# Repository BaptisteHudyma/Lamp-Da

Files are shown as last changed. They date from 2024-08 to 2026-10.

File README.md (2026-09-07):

# Lamp-Da

  

A programmable board integrated with a liion battery charger, battery balancer, multiple sensors and gpios (with 3 analog inputs).

This repository contains the bootloader, software and hardware files to create and program the board.

The system supports programming and charge throught the same USB-C port.

The board is made to fit into a 50mm tube.

## File details
- LampColorControler.ino: main class of the program, containing the setup and loop functions

## Physical build and architecture :

The electrical circuit and build files can be found in the **physical/electrical** folder.

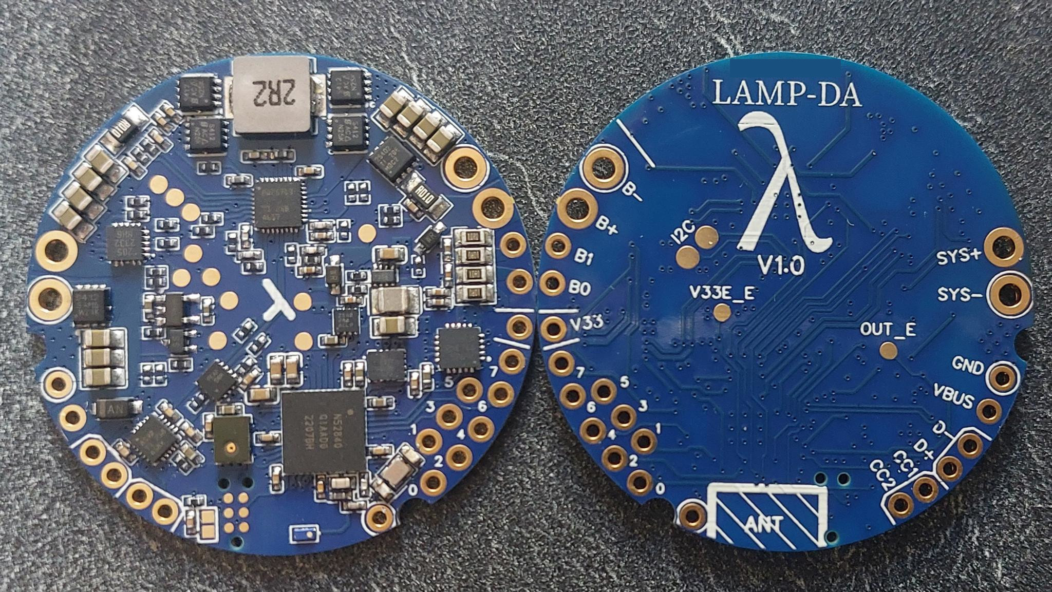
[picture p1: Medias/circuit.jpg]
electrical circuit


The PCB can be ordered directly assembled from JLC PCB, for a total cost of around 270$ for the minimal 5 pieces command (price drops with a more commands, until around 22$/circuit).

The circuit is 3 cells li-ion USB C charger & balancer & power source, that is also programmable via the same USB port.

The circuit features:
- USB-C 3S li-ion charger, based on BQ25713 ic.
- Battery balancing, based on BQ76905 ic.
- USB short circuit and EC protection, based on TPD8S300 ic.
- USB-C power negotiation, base on FUSB302B ic.
- Programable voltage source, from 3V to 20V, up to 3A, using the charge component
- 8 programmable IO pins (3 of which can be analog inputs, 4 can be pwm outputs). Based on nRF52840 ic.
- MEMS Microphone, placed away from parasitic ringing components.
- LSM6DS3TR IMU
- Bluetooth 5.1 low power, with 5/10m range.

- Multiple protection features (ESD spikes protection, USB voltage snubber, USB voltage limitation, ...)

Be careful:
- **NO REVERSE VOLTAGE PROTECTION FOR BATTERY**: it will blow the circuit right up
- **IO are 3.3V max**, any voltage greater will destroy the system

## Update the system

You can update the program without any tools :

Open a serial connection to the lamp, and use the "DFU" command to reset the system.
The system will appear on a computer as a USB file device.

You just need to copy the .uf2 file matching your lamp type into this USB device.
It will then reboot and update the system itself.

## Behavior

The code in this repo is made to be used as compact lanterns.

base behavior:
- The lamp starts and stops with one click.
- The luminosity can be raised by clicking than holding, and diminished by double-clicking than holding.

The battery level is displayed as a color gradient from green (high) to red (low).

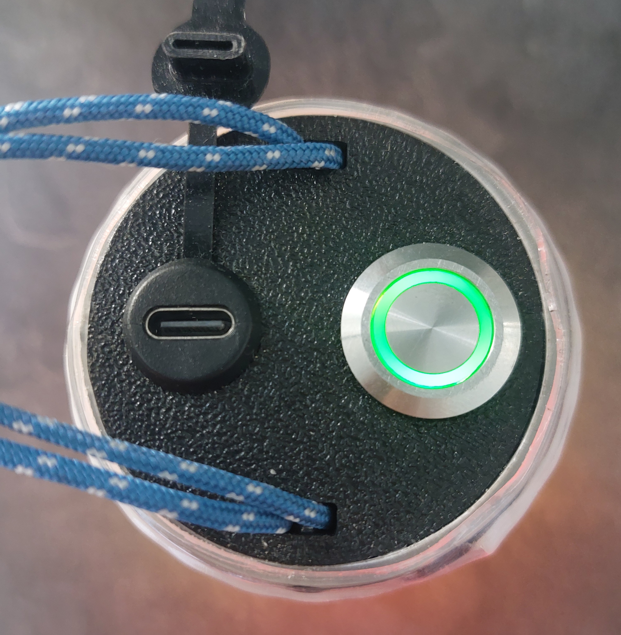
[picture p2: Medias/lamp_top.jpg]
battery levels


Error and alerts are displayed as blinking animations:
- low battery: slow red blinks
- critical battery: fast red blinks, emergency shutdown after short delay
- charging: breeze animation, changing color to indicate battery level
- incoherent battery readings: fast green/red blinks (battery reading do not match the set battery type)
- main loop too slow: fast fushia blinks
- temperature too high: fast orange blinks
- temperature extreme: emergency shutdown
- OTG failed: pink/yellow fast blink (failed to start the output power)
- bluetooth advertising: blue breeze animation
- hardware alert: fast purple/cyan blinks: generic alert to indicate the failure of a component, without recovery
- system off failed : fast purple/white blinks : system failed ot go to sleep, it will reset to default program and will need to be reflashed
- system in error state : fast pink/orange, then shutdown : reached an error state and is stuck here. Shutdown after five seconds
- unhandled: fast white blinks

### User defined behaviors
The user MUST define the target behavior for the target uses.

Some functions are defined in functions.h files, and must be implemented in functions.cpp
They allow the user to program the exact desired behavior.

Some user types are available for base models, in the user folder:
- cct: Program designed for a constant color temperature led strip.
- indexable: program designed for an indexable led strip wrapped around the lamp body
- simple: Program designed for a constant color led strip

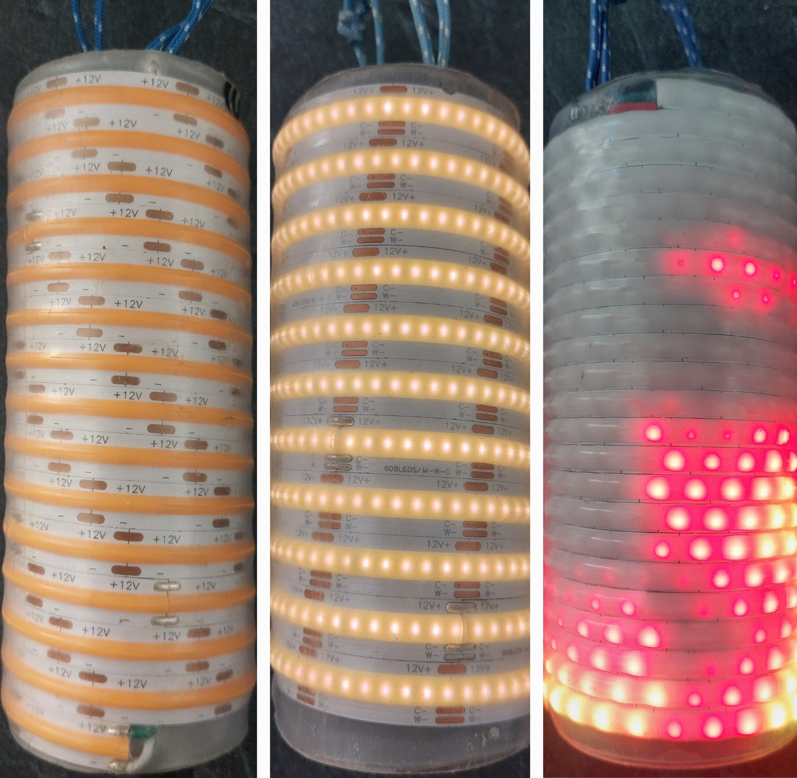
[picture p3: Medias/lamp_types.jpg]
The different lamps

Above: simple, cct, indexable

#### Bootloader flash
Out of factory, the board will miss a bootloader.

- Use a raspberry of any other linux system with gpios
- Use the open source program **openocd** as described in the **flashInfo** folder of this repository.

# Building the project

## Quick Setup

The supported platform to work with the project is:

 - Linux (Debian/Ubuntu/Archlinux/etc)

You will find a full guide on how to build the project here:

 - [Quick Setup](docs/QuickSetup.md) -- also lists all required dependencies

Note that after building documentation, it will be in `docs/html/index.html`

## Other Guides

You will find a guide on how to update the system via USB

 - [Update DFU](docs/Update.md)

You will find a guide on how to setup a virtual machine to build the project:

 - [Virtual Machine](docs/VirtualMachine.md) -- experimental, work-in-progress

You will find contribution guidelines to the project here:

 - [Contributing](docs/Contributing.md) -- **required to read for contributors**

As a beginner, you will find a guide to develop your own lighting mode here:

 - [Writing Modes](docs/WritingModes.md)

And a big thanks to all the people that helped !

 - [Thanks](docs/Thanks.md)

--------------------------------------------

Feel free to open an issue to ask your questions or give your ideas!

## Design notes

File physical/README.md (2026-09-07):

# Physical

Here are the main physical components to build the physical lamp.

## Electrical

Contains the PCB related file : components, routing, layers, everything to build the circuit, or order the circuit alreayd built.

## Objects

The physical objects to 3D print to assemble the lamp.

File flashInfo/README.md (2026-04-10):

# Flash process

When you receive the integrated circuit, the NRF52840 microcontroler will not have a bootloader.

I used a custom bootloader, [derived from adafruit](https://github.com/adafruit/Adafruit_nRF52_Bootloader), that allow the user to program the microcontroler via USB, and update the bootloader itself.

## Bootloader update
When pluging the usb cable, is the board is detected, a bootloader is already flashed.

It can be updated by copying the **update-lampda_nrf52840_bootloader** file into the board.
The board  should appears as a usb drive, with the name **LMBDBOOT**.

If the board  do not appear on the usb board (but is detected on the peripherals), it may be running a program.
The program as a Command Line Interface, that can put the board  in update mode.
Just connect to the board  with a serial connection (command `make monitor` from this repo will open the connection) and send the command `DFU`.

If the board is not detected after being pluged in, and do not appear as a peripheral, and cant be connected with serial, the board may be missing a bootloader.
Follow the next section.

## First time flash

To flash the bootloader for the first time, you must use a computer with GPIOs (I'm using a raspberry Pi) with openocd, or a JTAG connector.

You need to get the **lampda_nrf52840_bootloader**, next to this file.

Raspberry Pi pinout

Wire correspondance:

- white is the CL pin
- brown is the IO pin
- Black is the GND pin
- Red is the 3.3V pin

I use a TC2030 port, programable with a TC2030-MCP-NL cable.
The cable is expensive, but it is only useful once.

Circuit flash pins

You can run openocd next to the openocd.cfg to flash the board.

The process should end with no errors, and openocd should close itself.

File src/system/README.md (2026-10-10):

# File details
- global.h: main entry point for the program
- bsp: Board Support Package. Board specific implementations, under the application, above the HAL.
    - ble_services: BLE custom services
    - pd: PowerDelivery layer
    - balancer.h: handle the battery balancing, and some battery measurments
    - ble.h: BLE high level layer.
    - charging_ic.h: layer of the battery charging component
    - imu_wrappper.h: interaction layer of the imu
    - indicator.h: visual indicator controler (led in the button)
    - filesystem.h: handle the reading and writting of variables to memory
    - power_gate.h: the electrical gates to isolate output & vbus form each others
    - text_in.h: user text input and parsing
    - text_out.h: user text output
    - threads.h: Thread board support
- common: Common general use and interfaces
    - cmd_parser.h: Parse a command to extract its parameters
    - curves.h: define custom curve and curve sampling functions
    - elk_decoder.h: Decode elk messages
    - fft.h: implementation of the fft and assocated filtering
    - state_machine.h: generic state machine class, used for all main logic
    - time_utils.h: Useful time handling function
- component: Medium level physical components layer: button, bluetooth, IMU, ...
    - battery.h: handle the battery readings, for battery level
    - button.h: control the button. Takes callbacks for actions on multiple button pushes. Used to display stuf on the button if needed
    - charger.h: main high level logic to use the charger, as well as power switches
    - imu.h: the imu related operations
    - output_power.h: interface of the output voltage driver
    - sound.h: microphone main input point. Compute FFT and auto disable
    - strip.h: define the strip object (for now, only used in RGB lamp type)
    - time_handling.h: Real time handling
- driver: Low level hardware drivers
    - pd: PowerDelivery drivers
    - LSM6DS3: library to talk to the IMU. Adapted to this architecture
- ext: external libraries
    -  math8.h
    -  noise.h
    -  random8.h
    -  scale8.h
- hal: Hardware Abstraction Layer: implement the platform specific code. The implementation linked to those files is switched at compile time depending on the hardware target.
    - ble.h: bluetooth interfaces
    - gpio.h: programmable pins interface
    - i2c.h; i2c interface
    - filesystem.h: handle the reading and writting of variables to memory
    - pdm_handle.h: microphone interface (through PDM)
    - queues.h: Internal queue implementation
    - register.h: NRF52840 specific register access
    - serial.h: Serial connection interface
    - strip_impl.h: Indexable led strip driver
    - threads.h: Tasks and threads interface
    - time.h: time & chrono interface
- logic: handle high level system logic (Input actions, button presses, main state machine...)
    - alert.h: Handle the diffferent alerts raised by the program
    - behavior.h: controls the lamp behaviors: battery level, charger start and stops, ...
    - brightness_handle.h: handle the brightness logic
    - command_line_interface.h: handle serial communication. Location of the CLI capabilities
    - inputs_bluetooth.h: handle the bluetooth commands
    - inputs.h: what button actions does what
    - power_handler.h: High level handling of all power and battery related logic
    - statistics_handler.h: Keep track of the system use statistics
    - sun_timers.h: Logic of the sunset and sunrise timer. Sunset shutdown the system slowly, sunrise starts the system slowly
- utils: General functions and constants that everybody needs
    - colorspace.h: contain color space transition classes. Execution of those can be quite heavy for a microcontroler, beware !
    - constants.h: global constants used all around the program
    - input_output.h: define the gpio used for the button & indicator
    - utils.h: useful functions to make colors
    - vector_math.h: Handle 2D 3D and 4D vector math

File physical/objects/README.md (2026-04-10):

# Objects

The parts to print for the lampe are :

- `Lampda-Poles.stl` x3 : no supports needed
- `Lampda-LowerPart.stl` x1 : print with the logo facing down, no supports needed
- `Lampda-Top.stl` x1: print face down, with support for the first layer only

The lower part can be used without the logo, or with you own, using the `Lampda-LowerPart_no_logo.stl`

Depending on your printer settings, you may need to re-drill the holes using a 3.5mm drill.

# Bill of Material

BOM:

- cylindrical tube, external diameter 50mm, internal diameter 46mm, 12cm length
- 3x 21700 Li-ion batteries, in a 3S configuration
- 15cm clear heat shrink, 60mm diameter
- 6 wire USB-C, panel mounted
- 15cm of rope, 2mm diameter
- 2 cylindrical pins (35mmx3mm)
- 2 cylindrical pins (50mmx3mm)
- the PCB
- USB-C 6 pins RGB push button
- JST connector for battery (JST XH2.54MM, 4P, wire length 15CM)

USBC 6 pins RGB push button Clear shrink wrap

## Led Strips

The led strip lenght varies with strip width:

- a bit less than 4m for 5mm width
- around 2.5m for 8mm width

The led strips used in my case are :

- 2000K 12V, 8mm width, 480led/m COB strip : candle like color, used for the simple model
- indexable rgb 12V, 5mm width, 160led/m COB strip : indexable rgb strip, used for RGB model

# Assembly (not a tutorial)

The tube holes can be made accurately using the `hole_guides.stl`, and a 3mm drill.

The led strip can be wrapped using the `wrap_guide`, using the guide that matches the width of the led strip.

After the led strip is wrapped, shrink the shrink tube around it, and cut the excess.

Place the lower_part, and push the 50mm cylindrical through the tube and the lower_part.

Place the battery in the tube, and the 3 poles around it, with 2 vertical 35mm cylindrical pins. A drop of glue should be added at the 3 pole junction.

Place the PCB and close the assembly using the top part, and a final 50mm cylindrical pin. Do not forget to place the rope in the top part before pushing the cylindrical pin.

Printed assembly Full assembly

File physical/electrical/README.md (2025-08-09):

# Electrical manufacturing

The circuit has 134 component in total:
- 58 unique components
- 1 BGA

For manufacture, use the following parameters:
- 4 layers
- dimention 44x44mm
- 1.6mm thickness
- Material FR-4
- minimum hole size 0.3mm
- minimum track/spacing 4/4mil
- Surface finish ENIG (immersion gold 1U") : needed for BGA
- tented vias. No need to fill them, no via in pad
- 1oz copper. Can be more for top and bottom layer, but not needed

Manufacturing those are expensive: about 7200 us$ for 300 units, so about 24$ per unit.
Another test with a previous similar version : about 700$ for 10 units, so about 70$ per unit for small batches.

## Circuit details to come

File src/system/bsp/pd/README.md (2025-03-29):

USB pd is complicated.

This whole lib is a mess to understand, as much as it was to make work, so have some pity for yourself and do not step in.

The board can only be used as a data URP (USB slave, if you dont speak USB "nomenclature"), but can act as a power source (provider) or sink (consummer).
By default it should be used as a sink, but do whatever.

This lib handles power profile selection (as SINK) or power profile selection handling (as source), and power role swap.
The power role swap allows the system to go from sink to source, if requested by the plugged in device.

Here is an indicative map if you really really need to get going, or maybe just curious:
- the **drivers** folder contains the drivers for certain PD negociation chips. This project uses the FUSB302B for now, but this could change in the future.
- All files that starts with **tcpm** are the abstraction layer to the hardware. They link the drivers to the usb-PD algorithms.
- All the rest is a complex mess of the USB-pd algorithms, defined in the norm... It as been adapted to remove the unused functions (makes it lighter to compile/run), and prevent the reader from experiencing heavy nausea.

Some definitions to help in your quest:
- DFP: Downward facing port: USB host
- UFP: Upfront facing port: USB slave
- DRP: Dural role port: Can be host or slave, depending on context ! (an negociations)
- tcpm: Type C port management: interface between the hardware and software specific code
- tcpc: Type C port controler: generic usb type c controls
- PPS: Programmable Power Supply (from 3.3 to 20V in steps of 20mV)
- SPR: Standard power range (5V, 9V, 15V, 20V, PPS, to maximum 3/5A)
- EPR: Extended power range (up to 45V)
- GoodCRC: acknowledge message

- VCONN: special USB c line, used to power emarker chips. Not used in this program

USB pd message types
- DO: data object, prefix
- BDO: BIST DO, physical layer compliance testing
- PDO: Power DO, source power capabilities, or sink power requirements
- RDO: Request DO, used by a sink to require a target source PDO
- VDO: vendor DO, vendor specific informations
- BSDO: Battery Status DO, battery status informations
- ADO, Alert DO, to detail incidents that happened on the line

A standard cable should support 20V 3A.
To get more, you need to program something to speak to a marker chip in the cable.
We do not need it in this project, so you wont find code for it.

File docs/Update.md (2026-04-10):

# Updating the system

The system is packed with a DFU compatible bootloader, accessible by USB.
The DFU update is accessible by putting the system in update mode, using the following procedure :
- plug the system to a USB master device (eg: computer)
- Open a serial port at 115200 bauds
- test the connection by sending "v" to get system version, and "t" to get system type (simple, indexable, ...)
- type "DFU" to enter device firmware update
- The system reboots and appears has a mass storage device
- Put the .utf2 file corresponding to your system type into the mass storage device
- **touch nothing ! wait for the system to disconnect on its own**. it should take a minute at most.
- The system reboots with the updated firmware

Note : DFU stands for Device Firware Update

## Using a terminal

In a first terminal :
Listen to output on the serial port `cat -v < /dev/ttyACM0`

On another terminal :
Open the serial port `sudo chmod o+rw /dev/ttyACM0`
Send the "t" command : `echo -e 't\0' > /dev/ttyACM0`

You should see the type of the lamp on the first terminal.

Then send the "DFU" command : `echo -e 'DFU\0' > /dev/ttyACM0` to make the system enter the DFU mode.

## Using the Arduino IDE

In *Tools* tab, select the port where the system is connected. It will often be "/dev/ttyACM0" in linux.

Open the *Serial Monitor*, in the *Tools* tab.
Set the speed to 115200 bauds.

You can now send commands and receive answers from the system CLI.

On Linux, you have to check that the Arduino IDE can access the serial port.

## Using the repository

This repository has some built in tools to debug and update the system.
The command `make monitor` will open a serial monitor to the system on /dev/ttyACM0.

When using the `make upload-` commands, the upload of nexw code is automatic if the compilation succeeds.

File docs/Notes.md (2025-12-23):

# Notes

This is miscellaneous documentation around the project and its setup.

## How the build system works?

We are relying on Arduino and Adafruit's integrations to do a lot of things.
We want to use modern compiler features and some customization to our setup,
while we don't want to modify how Adafruit's platform core and libraries are
build.

On first build, we will thus first:

0. compile a "clean" `build-clean` target later used to detect how Arduino
   builds our sketch

Then, on all subsequent builds:

1. compile a "dry" `build-dry` target which will build core+libraries with the
   default setup
2. rebuild the sketch objects using our own custom setup (C++17, other flags)
4. compile a "final" `build` target which will let the `arduino-cli` reuse all
   the already-build objects, to produce a final artifact

This is a hack and sanity checks are in place to verify that the sketch have
been properly build (see `make verify-canary`)

## Check heap & stack

The system is still a low power microcontroller, so ram and flash are limited.
The program flash size is checked at compile time, but the heap/stack are not checked yet.

To analyze those, you can use the tool stackAnalyser.py, in the tools folder.
It should be used as so:
`python tools/stackAnalyser.py _build/simulator/indexable-simulator _build/simulator/CMakeFiles/simulator_indexable.dir/youPathToProject/src > stack.txt`
the generated file can be used to check the program running size.

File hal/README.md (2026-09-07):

# HAL (Hardware Abstraction Layer)

## Overview

This directory contains the Hardware Abstraction Layer (HAL) for the embedded system. The HAL provides a unified interface to hardware and simulation environments, allowing the same application code to run on both physical and simulated platforms.

## Structure

### `adafruit_nrf/`

Hardware implementation for the **NRF52840 microcontroller** using the Adafruit NRF core as the backend. This folder contains all device drivers and low-level interfaces specific to the NRF52840 platform.

### `simulator/`

Linux-based simulator implementation. Provides a virtual environment for development and testing using standard Linux interfaces and custom simulation variables.

## Platform Selection

At compile time, one of these two folders is linked into the build depending on the target platform:

- **Physical hardware**: links `adafruit_nrf/`
- **Simulation**: links `simulator/`

The application code remains unchanged regardless of the selected platform.

Any modification in the HAL must be done here, not in the generated files under generated/hal.

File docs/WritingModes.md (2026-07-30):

# Writing your own lighting mode

This document can be viewed as an introduction to development on the project,
as well as a way for beginners to write a new "lighting mode" for one of the
boards specified in this project.

## 0. Introduction: enable your first mode

First, the directory structure:

 - when writing a mode, you will mostly interact with code in `src/modes`
 - most board behaviors and lower level implementations is in `src/system`
 - the two worlds integrate together in `src/user`

The examples used in this guide are provided in `modes/examples`.

We will start with reading the `00_intro_mode.hpp` example:

```cpp
namespace modes::examples {

struct IntroMode : public BasicMode
{
  static void loop(auto& ctx) {
    ctx.lamp.fill(colors::Chartreuse);
    ctx.lamp.setBrightness(ctx.lamp.tick % ctx.lamp.getMaxBrightness());
  }
};

} // namespace modes::examples
```

We recommend that you put your modes inside a `modes::` namespace.

For example, if you are going to write some games for this board, feel free to
create a new `modes/custom/games/` directory, then a
`modes/custom/games/my_game_mode.hpp` file, with the following content:

```cpp
// keep the global namespaces clean! (& it gives you access to modes:: also)
namespace modes::games {

struct MyGameMode : public BasicMode
{
  /*
        ... some BasicMode callbacks implementation ...
  */
};

} // namespace modes::games
```

There are several rules while writing a mode:

 - your new mode object needs to inherit from `public BasicMode`
 - all your code shall be contained inside your new mode object
 - **all the mode methods and callbacks must be defined `static`**
 - all the mode members must be declared `static constexpr`

What you will observe as you experiment, is that mode structures such as
`IntroMode` and `MyGameMode` are completely state-less and are never
actually constructed during the runtime of the program. Hence, all the
following usages are **strongly discouraged**:

```cpp

int badGlobalVariable = 5;
const int badConstant = 3;
static int forbiddenStuff = 1;
// +everything shall be inside the mode struct!

struct VeryBadMode : public BasicMode
{
    //
    // the bad way
    //

    int badMember = 8;
    const int badConstant = 3;
    static int forbiddenWhat = 5;
    constexpr int badMistake = 1;

    static void loop(auto& ctx) {
      static int counter = 0; // !! do NOT use inline static, use StateTy !!
      counter += 1;
    }

    void _stateful_method() {

    }

    //
    // the good way
    //

    static constexpr int goodConstant = 0;

    static void _stateful_method(auto& ctx)
    {
      // ... some interaction with ctx.state ...
    }

    static constexpr int _stateless_helper(int ax, int ay, int bx, int by)
    {
      int dx = abs(ax - bx);
      int dy = abs(ay - by);
      return dx * dx + dy * dy;
    }
};

```

You can view that structure as *a collection of static callbacks* that
implements your mode.

**Note that only these callbacks will be called at runtime**.

For example, if we look at the default `BasicMode` implementation of the
`void loop(auto& ctx)` callback:

```cpp
  /** \brief Custom user mode loop function (default)
   *
   * Loop function each tick called whenever the mode is set as the currently
   * active mode by the user
   *
   * \param[in] ctx The current context, providing a interface to the local
   * state, the mode manager, as well as the hardware through its lamp object
   */
  static void loop(auto& ctx) { return; }
```

We see that by default, the `.loop()` callback does nothing.

Coming back at `00_intro_mode.hpp` we see that it implements it as follows:

```cpp
  static void loop(auto& ctx) {
    ctx.lamp.fill(colors::Chartreuse);
    ctx.lamp.setBrightness(ctx.lamp.tick % ctx.lamp.getMaxBrightness());
  }
```

Here the `ctx` object makes available two important members:

 - the `ctx.lamp` object that exposes to you user the lamp hardware
 - the `ctx.state` object that exposes to you your own mode state

We will later see how to make your mode stateful by defining a
custom `StateTy`.

Here, looking at the `LampTy` documentation, we see the following:

```cpp
  /// \brief Set brightness of the lamp
  void LMBD_INLINE setBrightness(const brightness_t brightness, /* ... */)

  /// \brief (indexable) Fill lamp with target color
  void LMBD_INLINE fill(uint32_t color)

  /// \brief (physical) Tick number, ever-increasing at 60fps
  volatile const uint32_t tick;
```

The `IntroMode` loop function thus fills the lamp with `colors::Chartreuse`
(see documentation for `modes/include/colors/palettes.hpp`) and then, vary
the brightness of the lamp depending on the current tick number.

One remark here, is that "colors" are meaningful only if the board is set up
with an RGB LED strip, meaning that this mode will fail if `make simple` or
`make cct` have been used during build.

To support multiple board flavors within a mode, use the following:

```cpp
struct IntroMode : public BasicMode
{
  static void loop(auto& ctx) {

    // this code is NOT included if "lamp flavor" is not RGB-indexable
    if constexpr (ctx.lamp.flavor == hardware::LampTypes::indexable) {
      ctx.lamp.fill(colors::Chartreuse);
    }

    ctx.lamp.setBrightness(ctx.lamp.tick % ctx.lamp.getMaxBrightness());
  }
};
```

If you tried to modify `modes/examples/00_intro_mode.hpp` by yourself during
this guide, you may have noticed that it is not compiled / not included at all.

This is because you need to *enable the mode* inside the global mode manager.

In order to do that, you can edit `src/user/indexable_functions.cpp` as
follows:

```cpp
// ...

#include "src/modes/default/fixed_modes.hpp"
#include "src/modes/legacy/legacy_modes.hpp"

// we include our mode file last
#include "src/modes/example/00_intro_mode.hpp"

namespace user {

//
// list your groups & modes here
//

using IntroGroup = modes::GroupFor<modes::examples::IntroMode>;
using ManagerTy = modes::ManagerFor<IntroGroup>;

/* !! you will need to comment the default mode manager config !!
using ManagerTy = modes::ManagerFor</* all the default groups */>;
```

Here, we declare a *mode group* named `IntroGroup` that contains only one mode,
our new `modes::examples::IntroMode` and nothing else. We are then able to pass
a list to the manager of all the groups we want to include in our
configuration, here our `IntroGroup` that only includes `IntroMode`.

## Custom mode commands

Some modes can enable custom commands, using the `hasButtonCustomUI` flag.
Enabling this flag will make the mode able to execute the `custom_click` and `custom_hold`, wich will respectively handle clicks and hold events.

Those functions can handle button clicks and hold, and return `true` when a command is handled by this mode to skip standard click behavior.

The custom user mode handling is enabled by a start command (3H), and disabled by turning the lamp off, with a 5C command.
The 5C command to turn of in custom user modes cannot be replaced by a custom user command.

## Hidden groups

It can be needed to have extra groups not accessible by standard actions.
The template option hiddenGroupCnt allows the programmer to add groups that wont be accessible by standard user inputs.

Be aware that once entered, those groups can be circulated by standard user commands.
Modes in thoses groups can also be saved as favorites and other standard actions.
The only difference with the *standard* groups will be the way to go to those groups.

A manager can only be created with at least one accessible group.

Enter an hidden group simply using the `enter_group` method of the manager, with the id of the hidden group as a parameter.

The types to use for managers with hidden groups is `ManagerFoHiddenConfig` and `ManagerForHiddenGroups`.

Example:
```cpp
using ManagerTy = modes::ManagerForHiddenGroups<1,
                                                group1,
                                                group2,
                                                group3,
                                                group4  // group 4 is an hidden group
                                                >;
```

```cpp
using ManagerTy = modes::ManagerForHiddenGroups<3,
                                                group1,
                                                group2, // group 2 is an hidden group
                                                group3, // group 3 is an hidden group
                                                group4  // group 4 is an hidden group
                                                >;
```

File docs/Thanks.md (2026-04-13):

# Thanks !

Thanks to everyone who helped this project and its development :)
I'm grateful to all of you for the help and support during this absolute madness of a project, for a near perfect result !

## In no particular order

**Michel** for the initial inspiration and help to create my first lamp, giving me the will to do more.

**2K6** for his software architecture and deployment knowledge, all of this would still be a prototype without you.

**Chouette** for the first ever test, and broken lamp. The first user of one of my lamps, and it did not work. Also responsible for the name Lamp-da !

**Epsilon** for his capability to destroy anything, you figured every way something can break. I designed a sturdy creation thanks to you.

**Orvus** for the update application. A necessary functionality that we missed for a long time.

**M.Besson** for the in depth electronic technical review. I would have made at least 2 more prototypes without your help.

**2K6**, **Chouette**, **Eclipse**, **Epsilon** for the moral support during this two years madness. The word "lamp" was said too much during this period.

**Chouette**, **Elisa**, **Nyx** for the first ever lamp factory (2022). You made the first 8 lamps that lasted some time.

**Chouette**, **Epsilon**, **Le Cartographe** for the first tests and destruction of the first prototypes, they did not last long.

**Artefact** for the availability of "l'Atelier Synergique". No factory no production without you and your incredible workshop handling.

And for the big lamp factory, in no particular order :
**Kuitochette, Papi, Atreyu, Greg, Piers, Bobby, le scout, Scarlett, Chouette, Le Cartographe, Epsilon, Latha, Fourmiz, Shadal, 86, Incandescent, Dova, Larabou, Eclipse, Lem, Orvus, Soupole, 2K6, Legist, Toxico, Yoyo, Julot, Kundun, Valaar, Neudz**

You made this possible and I'm forever grateful.

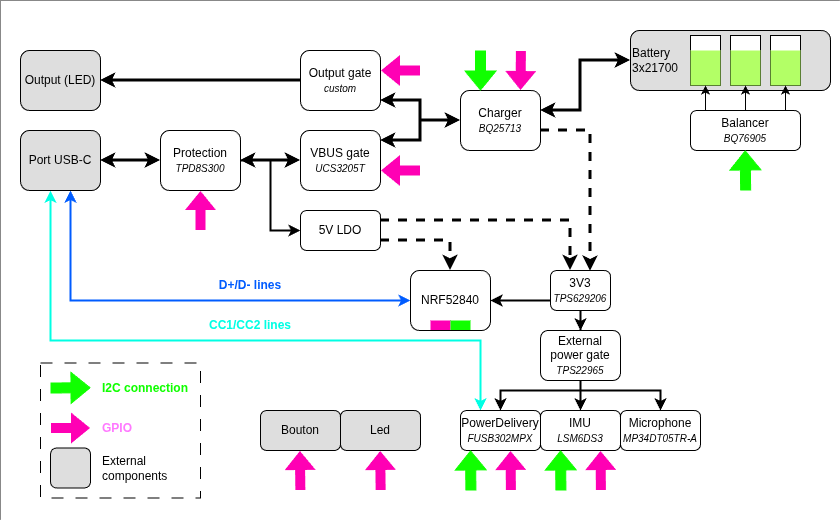
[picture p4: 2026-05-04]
Medias/electrical_global_view.png

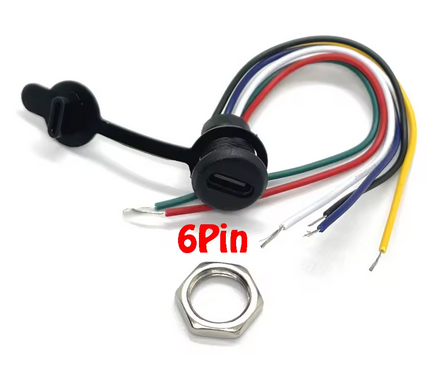
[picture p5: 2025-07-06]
Medias/6pin_usb_c.png

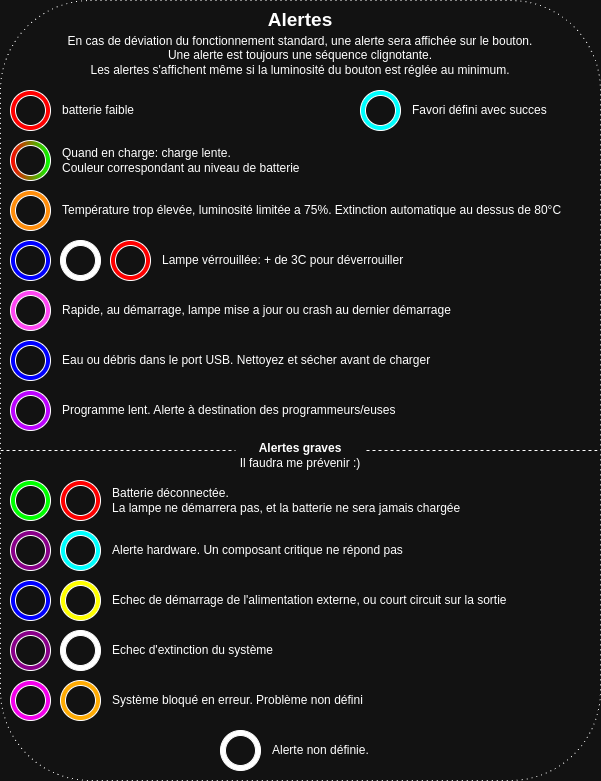
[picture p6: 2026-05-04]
Medias/Diagramme_commandes.Alertes.png

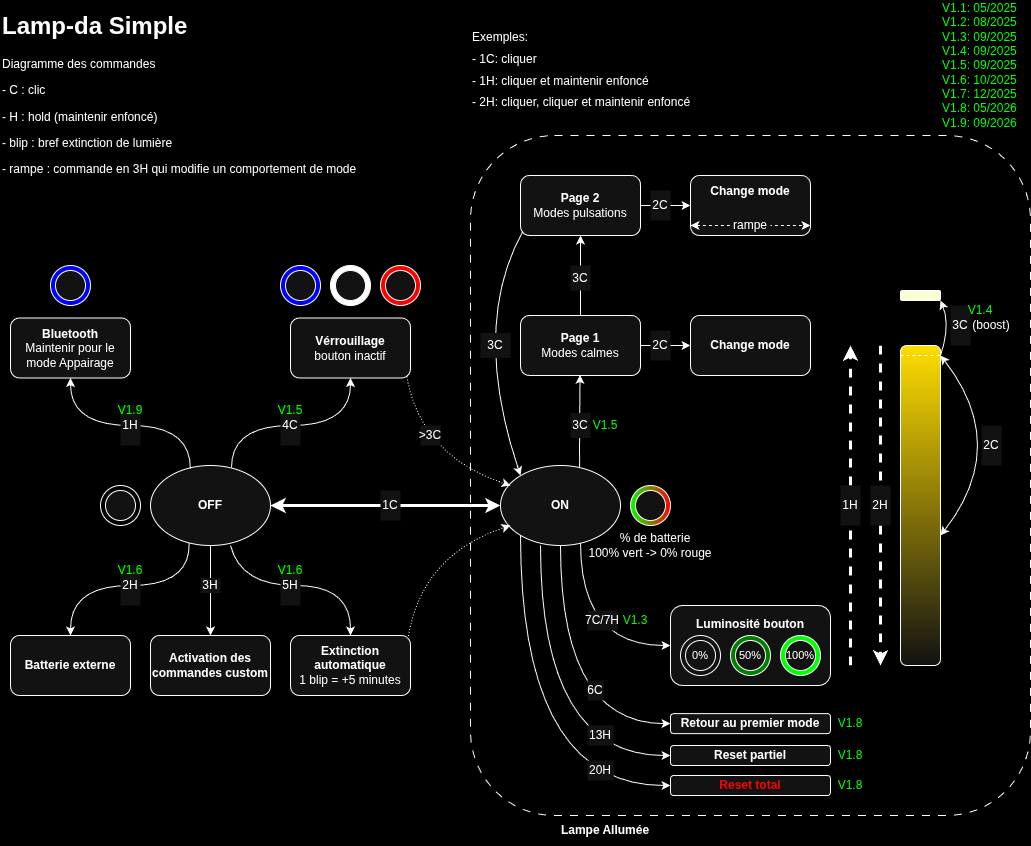
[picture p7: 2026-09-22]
Medias/Diagramme_commandes.jaune.png

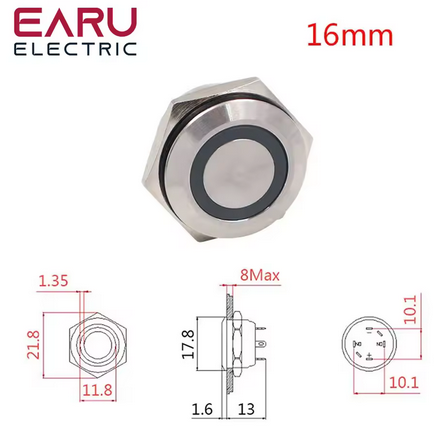
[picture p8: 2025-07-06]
Medias/rgb_push_button.png

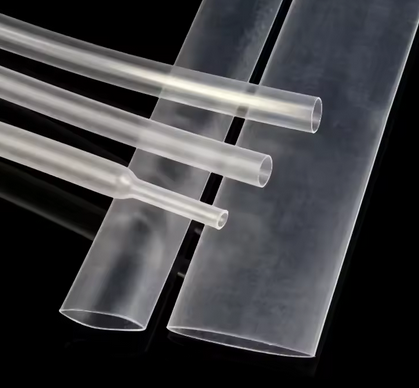
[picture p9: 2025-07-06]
Medias/clear_shrink_wrap.png

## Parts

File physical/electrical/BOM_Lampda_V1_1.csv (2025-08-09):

ID | Name | Designator | Footprint | Quantity | Manufacturer Part | Manufacturer | Supplier | Supplier Part | Price
1 | 470nF | C1 | C0402 | 1 | CC0402KRX5R9BB474 | YAGEO(国巨) | LCSC | C513552 | 0.043
2 | 1uF | C2,C22,C39,C48,C53,C55,C58 | C0402 | 7 | HGC0402R5105K500NTEJ | Chinocera(华瓷) | LCSC | C7472948 | 0.013
3 | 100nF | C3,C7,C11,C28,C40,C41,C46,C47,C50,C51 | C0402 | 10 | 0402B104K250CT | Walsin(华新科) | LCSC | C301930 | 0.002
4 | 47nF | C4,C25 | C0402 | 2 | TCC0402X7R473K500AT | CCTC(三环) | LCSC | C880605 | 0.001
5 | 22uF | C5,C18,C19,C32,C34,C35,C36,C43,C52,C56,C59 | C0805 | 11 | CC0805MKX5R8BB226 | YAGEO(国巨) | LCSC | C784585 | 0.064
6 | 220pF | C6,C10 | C0402 | 2 | TCC0402X7R221K500AT | CCTC(三环) | LCSC | C466236 | 0.001
7 | 33nF | C8,C12 | C0402 | 2 | CC0402KRX7R9BB333 | YAGEO(国巨) | LCSC | C106862 | 0.002
8 | 680pF | C9,C29 | C0402 | 2 | 0402B681K500NT | FH(风华) | LCSC | C1541 | 0.001
9 | 820pF | C13 | C0402 | 1 | 0402B821K500NT | FH(风华) | LCSC | C1543 | 0.001
10 | 2.2uF | C14,C21 | C0402 | 2 | C0402C225M9PACTU | KEMET(基美) | LCSC | C452745 | 0.016
11 | 15pF | C15 | C0402 | 1 | 0402CG150J500NT | FH(风华) | LCSC | C1548 | 0.001
12 | 10pF | C16,C31 | C0402 | 2 | GJM1555C1H100JB01D | muRata(村田) | LCSC | C85874 | 0.014
13 | 33pF | C17 | C0402 | 1 | HGC0402G0330J500NTEJ | Chinocera(华瓷) | LCSC | C482484 | 0.001
14 | 1.8nF | C20 | C0402 | 1 | TCC0402X7R182K500AT | CCTC(三环) | LCSC | C696873 | 0.001
15 | 10nF | C23 | C0402 | 1 | TCC0402X7R103K500AT | CCTC(三环) | LCSC | C688874 | 0.001
16 | 10uF | C24,C27,C30 | C0805 | 3 | HGC0805R7106K250NSLJ | Chinocera(华瓷) | LCSC | C33546010 | 0.043
17 | 100pF | C26,C38,C54 | C0402 | 3 | CC0402JRX7R9BB101 | YAGEO(国巨) | LCSC | C281750 | 0.002
18 | 0.5pF | C33 | C0402 | 1 | CC0402CRNPO9BNR50 | YAGEO(国巨) | LCSC | C327230 | 0.002
19 | 4.7uF | C37,C45,C49,C60 | C0603 | 4 | TCC0603X5R475K250CT | CCTC(三环) | LCSC | C5360844 | 0.009
20 | 0.8pF | C42 | C0603 | 1 | 0603CG0R8C500NT | FH(风华) | LCSC | C501845 | 0.003
21 | 1nF | C44 | C0402 | 1 | CC0402KRX7R8BB102 | YAGEO(国巨) | LCSC | C541372 | 0.001
22 | 22uF | C57 | C0805 | 1 | GCM21BD70J226ME36L | muRata(村田) | LCSC | C2981736 | 0.207
23 | ANT1608LL14R2400A | F1 | ANT-SMD_3P-L1.6-W0.8_ANT1608LL14R2400A | 1 | ANT1608LL14R2400A | YAGEO(国巨) | LCSC | C723550 | 0.433
24 | 2.2uH | L1 | IND-SMD_L7.0-W6.6_FXL0630 | 1 | FXL0618-2R2-M | cjiang(长江微电) | LCSC | C524593 | 0.299
25 | DFE252012PD 2.2uH | L3 | L1008 | 1 | DFE252012PD-2R2M=P2 | muRata(村田) | LCSC | C237482 | 0.225
26 | 4.7nH | L5 | L0402 | 1 | CLH1005T-4N7S-S-NP | chilisin(奇力新) | LCSC | C142221 | 0.004
27 | MP34DT05TR-A | MIC | MIC-SMD_5P-L3.0-W4.0-P0.85-BL | 1 | MP34DT05TR-A | ST(意法半导体) | LCSC | C2688664
28 | SIS412DN-T1-GE3 | MOS1,MOS2,MOS3,MOS4 | POWERPAK-1212-8_L3.0-W3.0-P0.65-LS3.3-BL | 4 | SIS412DN-T1-GE3 | VISHAY(威世) | LCSC | C111309 | 0.193
29 | DMP3018SFVQ-7 | Q1,Q2 | DFN-8_L3.3-W3.3-P0.65-BL-2 | 2 | DMP3018SFVQ-7 | DIODES(美台) | LCSC | C5245379 | 0.355
30 | BSS138W-TP-ES | Q3 | SOT-323-3_L2.0-W1.3-P1.30-LS2.3-BR | 1 | BSS138W-TP-ES | ElecSuper(静芯微) | LCSC | C5224284 | 0.022
31 | 100kΩ | R1,R17 | R0402 | 2 | CR0402F100KQ10Z | EVER OHMS(天二科技) | LCSC | C881385 | 0.001
32 | 10Ω | R2,R4,R9,R19,R21,R22,R23,R27 | R0402 | 8 | 0402WGF100JTCE | UNI-ROYAL(厚声) | LCSC | C25077 | 0.001
33 | 10kΩ | R3,R18,R25,U2,U3,U4,U5,U7,U8,U15,U24,U25 | R0402 | 12 | RAT021002FTH | RALEC(旺诠) | LCSC | C5119777 | 0.002
34 | 470Ω | R5 | R0402 | 1 | AECR0402F470RK9 | RESI(开步睿思) | LCSC | C352415 | 0.005
35 | 40.2kΩ | R6,R20,R26 | R0402 | 3 | CR0402F40K2Q10Z | EVER OHMS(天二科技) | LCSC | C881147 | 0.001
36 | 619kΩ | R7,R13 | R0402 | 2 | RC0402FR-07619KL | YAGEO(国巨) | LCSC | C327332 | 0.001
37 | 137kΩ | R8,R24 | R0402 | 2 | TC0250D1373TCE | UNI-ROYAL(厚声) | LCSC | C778430 | 0.017
38 | 1Ω | R10 | R0402 | 1 | CR0402F1R00Q10Z | EVER OHMS(天二科技) | LCSC | C881121 | 0.002
39 | 4.99Ω | R11,R12 | R0402 | 2 | 0402WGF499KTCE | UNI-ROYAL(厚声) | LCSC | C25122 | 0.001
40 | 30kΩ | R14,R16 | R0402 | 2 | 0402WGF3002TCE | UNI-ROYAL(厚声) | LCSC | C25776 | 0.001
41 | 4.7kΩ | R15,R32,R33 | R0402 | 3 | RMC04024K7JN | Tyohm(幸亚电阻) | LCSC | C269679 | 0.002
42 | 100Ω | R31 | R0402 | 1 | 0402WGJ0101TCE | UNI-ROYAL(厚声) | LCSC | C25138 | 0.001
43 | 10mΩ | RAC1,RSR1 | R1206 | 2 | HoJLR1206-1W-10mR-1% | Milliohm(毫欧) | LCSC | C2903499 | 0.065
44 | TPD8S300 | U1 | WQFN-20_L3.0-W3.0-P0.40-TL-EP | 1 | TPD8S300RUKR | TI(德州仪器) | LCSC | C571205 | 0.978
45 | LSM6DS3TR | U6 | LGA-14_L3.0-W2.5-P0.50-TL | 1 | LSM6DS3TR | ST(意法半导体) | LCSC | C95230 | 1.466
46 | NRF52840-QIAA-R | U9 | AQFN-73_L7.0-W7.0-P0.50-BL-EP4.8 | 1 | NRF52840-QIAA-R | NORDIC | LCSC | C190794 | 4.126
47 | TPS629206QDRLRQ1 | U10 | SOT-583-8_L2.1-W1.6-P0.50-LS1.6-BL | 1 | TPS629206QDRLRQ1 | TI(德州仪器) | LCSC | C5219296 | 0.748
48 | PTVS24VS1UR | U11 | SOD-123_L2.6-W1.7-LS3.5-RD | 1 | PTVS24VS1UR | FUXINSEMI(富芯森美) | LCSC | C5380693 | 0.039
49 | BQ76905RGRR | U12 | VQFN-20_L3.5-W3.5-P0.50-TL-EP2.1 | 1 | BQ76905RGRR | TI(德州仪器) | LCSC | C22394458 | 2.794
50 | UCS3205T-E/Q8A | U13 | VQFN-19_L3.0-W3.0-P0.50-TL-EP | 1 | UCS3205T-E/Q8A | MICROCHIP(美国微芯) | LCSC | C1518729 | 4.466
51 | 220nF | U14,U18,U19,U22 | C0402 | 4 | FCC0402X224K160AT | FOJAN(富捷) | LCSC | C5137633 | 0.002
52 | FUSB302MPX | U16 | MLP-14_L2.5-W2.5-P0.50-BL-EP | 1 | Fusb302mpx | onsemi(安森美) | LCSC | C442699 | 1.082
53 | AP2205-50W5-7 | U17 | SOT-25-5_L2.9-W1.6-P0.95-LS2.8-BL | 1 | AP2205-50W5-7 | DIODES(美台) | LCSC | C5378676 | 0.219
54 | BQ25713RSNR | U20 | QFN-32_L4.0-W4.0-P0.40-TL-EP2.8 | 1 | BQ25713RSNR | TI(德州仪器) | LCSC | C2878935 | 1.167
55 | TPS22965DSGR | U21 | UDFN-8_L2.0-W2.0-P0.50-TL-EP | 1 | TPS22965DSGR | TI(德州仪器) | LCSC | C122837 | 0.141
56 | PMEG3010BEA,115 | U26,U27,U28 | SOD-323_L1.7-W1.3-LS2.5-RD | 3 | PMEG3010BEA,115 | Nexperia(安世) | LCSC | C2937140 | 0.056
57 | 32MHz | X1 | CRYSTAL-SMD_4P-L2.0-W1.6-BL | 1 | Q22FA12800025 | EPSON(爱普生) | LCSC | C187794 | 0.259

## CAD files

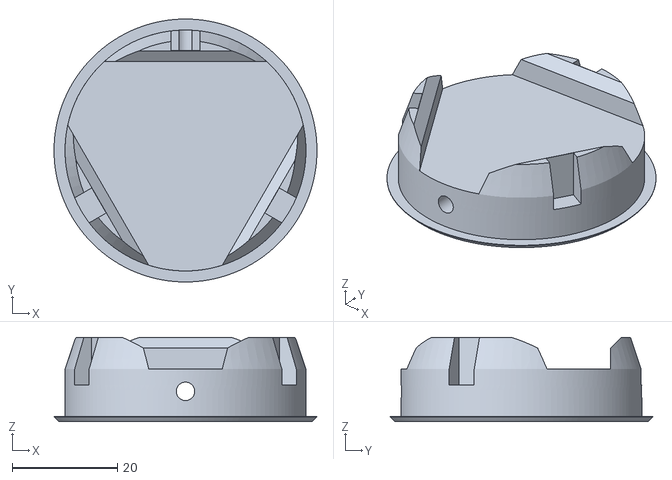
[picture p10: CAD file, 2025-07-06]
physical/objects/Lampda-LowerPart_no_logo.stl
50.0 x 50.0 x 16.0

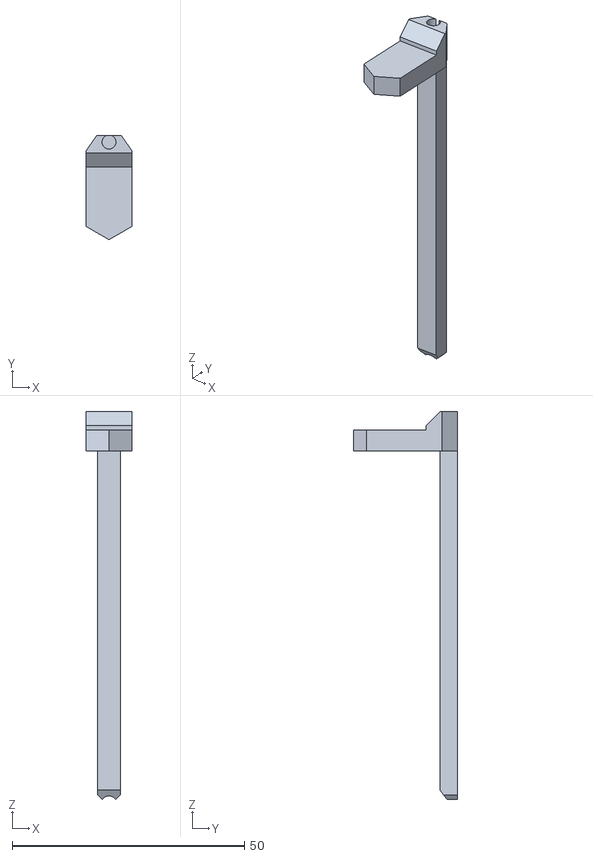
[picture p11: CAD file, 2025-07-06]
physical/objects/Lampda-Poles.stl
10.0 x 22.5 x 83.5

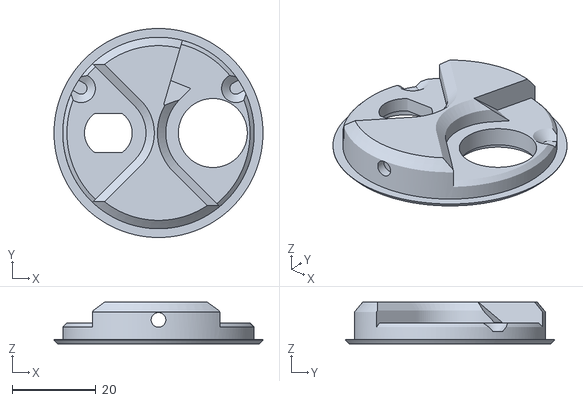
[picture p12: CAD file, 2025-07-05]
physical/objects/Lampda-Top.stl
50.0 x 50.0 x 10.0

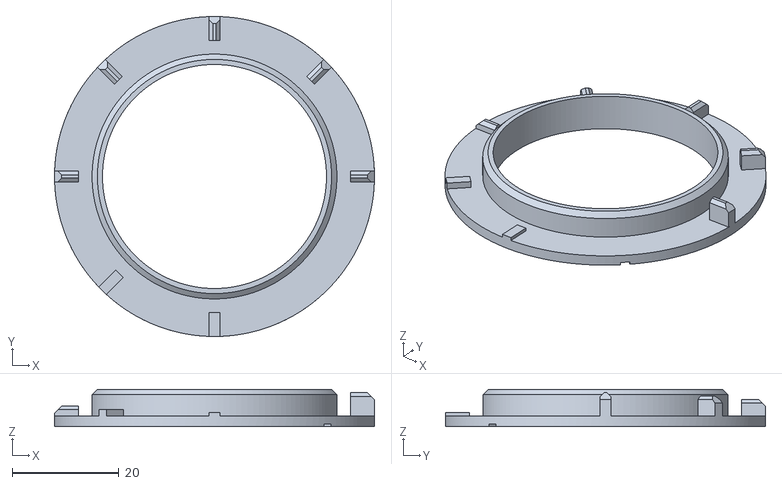
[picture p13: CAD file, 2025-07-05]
physical/objects/wrap_guide_5mm.stl
60.0 x 60.0 x 7.00

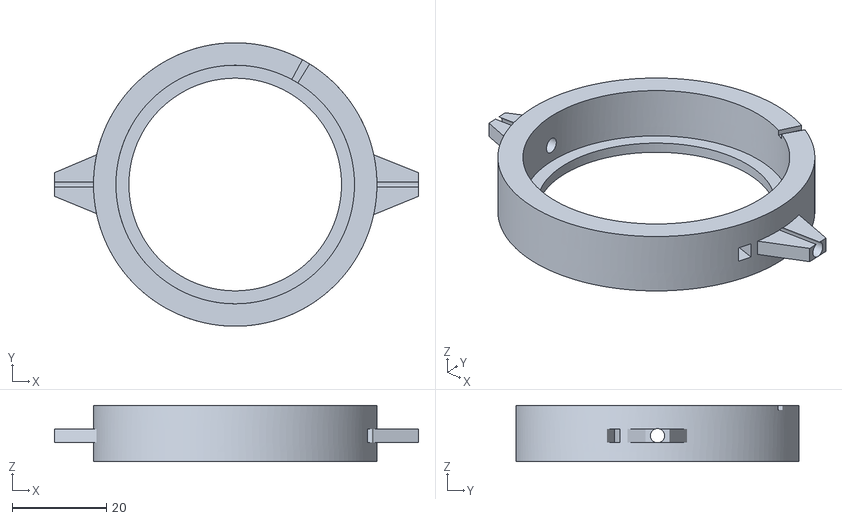
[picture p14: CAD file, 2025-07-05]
physical/objects/hole_guides.stl
77.0 x 60.0 x 11.9

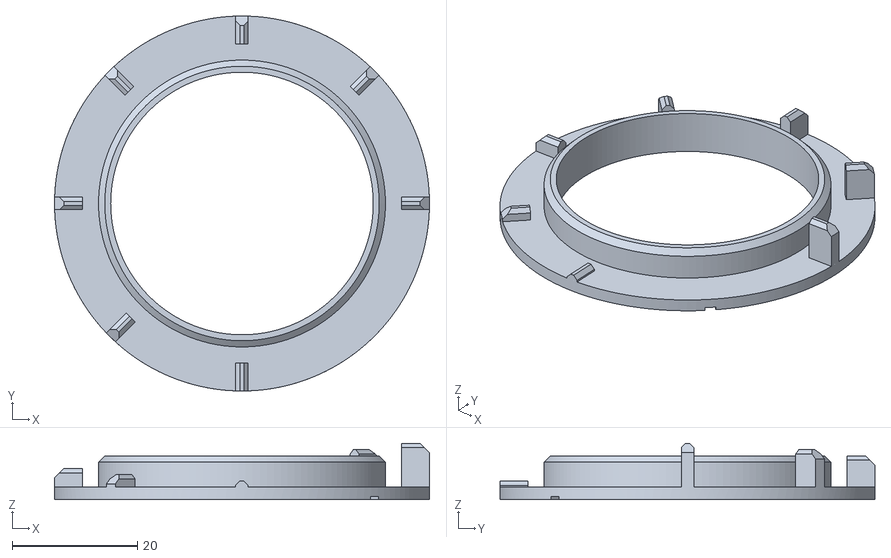
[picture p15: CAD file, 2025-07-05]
physical/objects/wrap_guide_8mm.stl
60.0 x 60.0 x 9.00

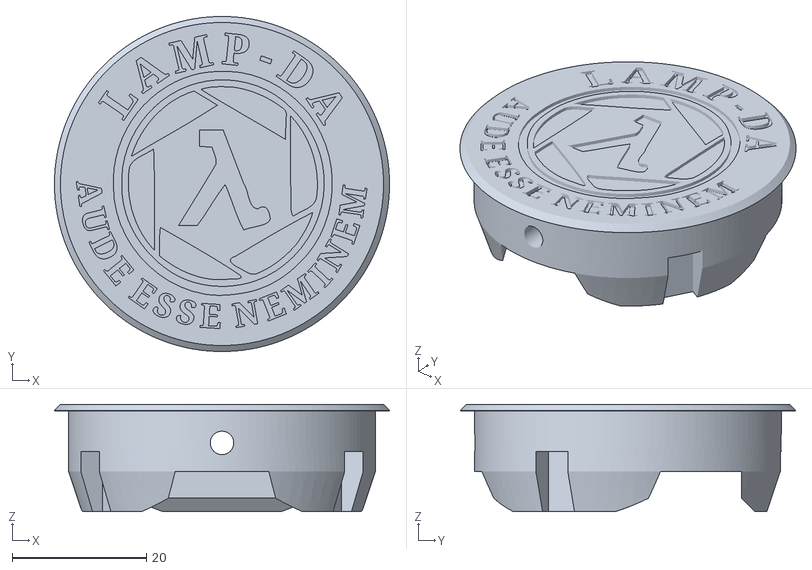
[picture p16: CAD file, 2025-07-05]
physical/objects/Lampda-LowerPart.stl
50.0 x 50.0 x 16.0

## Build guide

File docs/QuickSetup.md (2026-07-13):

# Quick Setup

First clone the repository:

```sh
git clone https://github.com/BaptisteHudyma/Lamp-Da.git LampColorControler
cd LampColorControler
git submodule update --init
```

This project uses the Arduino SDK, you will need to install several
dependencies before being able to build the project and upload your
firmware.

## Useful Linux packages

For reference, if you are on a `Debian/Linux (debian12,bookworm)` system, here
is a list of packages that you may need to use this project:

 - `build-essential gcc g++ clang clang-format make cmake git` for development
 - `python3 python3-venv python-is-python3` to flash the board & use tools
 - optionally, if you want to build the simulator:

    - `libsfml-dev` if you are on a platform that have `SFML 2.5.1` or greater
    - `libx11-dev libxrandr-dev libxcursor-dev libxi-dev libudev-dev`,
      `libfreetype-dev libvorbis-dev libflac-dev` and
      `libopenal-dev libalut-dev` if you do not have `SFML2`, as the simulator
      build system will try to download and compile
      `SFML 2.6.1` from source.

Depending on your setup (Ubuntu, WSL, Fedora, Archlinux, …) you may need to
install other packages, such as `arduino-cli` or `arduino-ide` as described
below.

## Other depencies

You will need to:

 - Install the Arduino IDE and verify that `arduino-cli` is accessible in path
 - Install the Adafruit nRF52 board support (version 1.7.0) [as described here](https://github.com/BaptisteHudyma/LampDa_nRF52_Arduino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)
 - Replace the content of the `$HOME/.arduino15/packages/adafruit/hardware/nrf52` by the content of the [above repository](https://github.com/BaptisteHudyma/LampDa_nRF52_Arduino)
 - Install [`adafruit-nrfutil`](https://github.com/adafruit/Adafruit_nRF52_nrfutil) from PyPI
 - Install the [`arduinofft`](https://docs.arduino.cc/libraries/arduinofft/) libraries

To check that `arduino-cli` is available in path, you can run:

```sh
arduino-cli version
```

If your system does not package `arduino-cli` or if it's not working for you,
you may try the following recipe to make it available locally:

```sh
# also download+install arduino-cli in $SRC_DIR/_build/arduino-cli/
cd LampColorControler
make arduino-cli-download
```

Now that `arduino-cli` is available, if you find yourself in trouble
installing the Arduino dependencies by hand, you can use the following
to install everything locally:

```sh
# download+install all dependencies (~1.4Go) in $SRC_DIR/_build/arduino-cli/
cd LampColorControler
make safe-install
```

## Building the project

Once all dependencies are set up, you will be able to build the project
as follows:

```sh
# build project assuming simple lamp type
cd LampColorControler
make simple
```

If you are working on the `indexable` variant of the lamp, you
can use:

```sh
# build project assuming simple lamp type
cd LampColorControler
make indexable
```

When changing lamp type or adding a new file to the sketch, use:

```sh
cd LampColorControler
make clean
make indexable
```

You can also use the `clean-artifacts` recipe to remove only the output
binaries, and to only rebuild what is necessary:

```sh
# remove build artifacts & rebuild the project
cd LampColorControler
make clean-artifacts {simple,cct,indexable} # pick one
```

## Uploading to board

After plugging your board, you should be able to upload as follows:

```sh
# use upload-indexable if you are working with indexable
cd LampColorControler
make upload-simple
```

Note that `upload-{simple,cct,indexable}` checks that you have build the
associated `{simple,cct,indexable}` recipe, and that you may get an error
message if you are mixing up the different versions.

You may need to configure the serial port of the board before uploading:

```sh
# by default LMBD_SERIAL_PORT is /dev/ttyACM0
cd LampColorControler
LMBD_SERIAL_PORT=/dev/ttyACM1 make upload-simple
```

Once your board is running, to connect to its serial monitor, use:

```sh
# use LMBD_SERIAL_PORT as above to configure the serial port
cd LampColorControler
make monitor
```

If you have a `virtualenv` somewhere with `adafruit-nrfutil` already
installed, you may setup a link to explicitly use it:

```sh
# the Makefile will source $SRC_DIR/venv/bin/activate
cd LampColorControler
ln -s venv path/to/other/virtualenv
make clean-artifacts upload-indexable
```

## Building the documentation

To build the documentation, you must have `doxygen` installed:

```sh
# use "make clean-doc doc" to force documentation rebuild
cd LampColorControler
make doc
```

You will be able to preview the documentation as follows:

```sh
$(BROWSER) ./docs/html/index.html
```

## Building the simulator

If you want simulate a view of an "indexable mode" animation and have the
[SFML](https://www.sfml-dev.org/) installed:

```sh
cd LampColorControler
make simulator
./_build/simulator/indexable-simulator
```

This may build the SFML library if `SFML 3.0.1` is not available locally, and
it will fail if some of the required dependencies are missing.

Note that the compiler used is `/usr/bin/c++` by default, and as we are using
modern C++17 features as well as things like `-fconcepts` you will require an
up-to-date local compiler -- here "up-to-date" typically means something from
2020 :)

## Cleaning up

There are several `clean-*` recipes available:

```sh
# "quick" clean recipes
make clean-artifacts # removes output build artifacts, use it to force rebuild
make clean-doc # removes output "index.html" artifact, use it to force rebuild
make clean-simulator # removes simulator artifacts, use it to force rebuild :)

# "full" clean recipes
make clean # must be called when changing LAMP_TYPE, or if you added a .cpp file
```

Once you're finished with your work on the project:

```sh
# this removes build artifacts AND all local dependencies
cd LampColorControler
make mr_proper
```

Note that this last method WILL remove all the locally installed dependencies,
that may be very expensive to install again (more than a gigabyte of setup).

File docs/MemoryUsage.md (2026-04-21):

# Memory usage

# Flash usage

Statically checked after compilation, displayed as a percentage of the total available flash.

## Stack and RAM usage

Compile the project, than run :
`python tools/ramAnalyser.py --elf _build/objs/LampColorControler.ino.elf --sudir ./_build/objs/`

This program will fail on a stack budget overflow.
It shows if the program uses dynamic memory allocations, and the path of most stack use.

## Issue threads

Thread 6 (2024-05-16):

Add IMU support

BaptisteHudyma, 2024-05-16:
In branch **main**

Add support for the IMU (start, stop, measure, filter)

BaptisteHudyma, 2025-02-24:
Handled in #63

Closed 2025-04-20.

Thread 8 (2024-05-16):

Enable USB OTG

BaptisteHudyma, 2024-05-16:
in branch **main**

The user should be able to enable the USB OTG function.

Default the output to 5V 1A max.

BaptisteHudyma, 2024-11-17:
The current circuit does not seem to be able to start the EN_OTG signal. This makes this task difficult to test

Closed 2024-12-03.

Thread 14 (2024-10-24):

Augment microphone sampling frequency

BaptisteHudyma, 2024-10-24:
The current sampling frquency is 16kHz.

It should be updated to fit a higher standard (like 22Hz).

The FFT part must be updated in line with this.

BaptisteHudyma, 2024-11-19:
This has became useless with the fft refactor, the new fft is corrected to handle the correct frequencies

Closed 2024-11-19.

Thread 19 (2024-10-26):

Add system load measurment

BaptisteHudyma, 2024-10-26:
Add the capacity to control the system load at all times.

This will add the ability to estimate the battery health, and capacity.
This will add the ability to stop the charging process based on the current consumption.

BaptisteHudyma, 2024-12-03:
It works but the resolution of 256mA is too coarse for a good estimation of battery life & idle current consumption

Closed 2024-12-03.

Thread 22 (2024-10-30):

Optimise memory space

BaptisteHudyma, 2024-10-30:
The current string key and uint32 value is not optimised for space and has the following issues:
- long read time (several milliseconds/32 bits)
- long write time (tens of milliseconds/32 bits)
- non optimised space, because of the strings

It should be modified so the string is replaced by the hash provided for strings.
The 32 bit number beeing written should also be put in the file in direct form, not as a string like currently.

Closed 2024-10-30.

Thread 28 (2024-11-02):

Add slow charge UI

BaptisteHudyma, 2024-11-02:
When the charging current is low (< 500mA), the user must be informed by a special UI.

Options:
- Dedicated alert (can be disturbing when it's desired behavior)
- slow charging animation (not obvious for the average user)
- charging animation with a low battery color (not obvious that the battery is still charging)

BaptisteHudyma, 2024-11-19:
A slow charge animations has been programmed.

For now it's just a blinking instead of the classic breeze animation for the charge.

This UI shall be revised in a future MR.

Closed 2024-11-19.

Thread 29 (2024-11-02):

Add USB charger detection

BaptisteHudyma, 2024-11-02:
The board shall be able to detect when a charge cable that is plugged in is wired to a charger.

The USB documentation notes that in this case, D+ & D- will be tied togethers, and a 1.5A current will be available.
We must check if this is true on proprietary chargeurs.

The state of CC1 CC2 pins can also give a clue.

BaptisteHudyma, 2024-11-04:
The CC part was done in #24.
The detection of legacy USB A charger (BC1 protocol) is maybe not possible with the current hardware.

This issue should be left open until BC1 is supported.

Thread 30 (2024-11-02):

Handle charging component alerts

BaptisteHudyma, 2024-11-02:
Handle the alerts & error flags of :
- the charger component
- the usb protection component
- the usb negociation component

The most important is the charger component.
The others have only simple flags that can help to debug the system.

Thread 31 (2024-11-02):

Add CV charging mode

BaptisteHudyma, 2024-11-02:
When battery is full (after a CC charge), the chargeur should switch to CV charge.

To do so, it should incrementally lower the charging current when the battery voltage goes over the target voltage (simple solution) until the current drops below a threshold. After that the charge is considered finished.

Closed 2025-04-06.

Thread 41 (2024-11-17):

Harmonize the battery level ramp

BaptisteHudyma, 2024-11-17:
The battery level of a Liion is not linear, and currently we have a dumb way to convert from the voltage of the liion to the actual battery level (simple 3 curve approximation).
This level is remaped to the "safe" battery level (the max and min voltage for the battery, defined by the user).
(Check the battery.cpp file)

This method is imprecise, and breaks occasionally the logic of the application (eg: low battery shutdown).
It should be replaced by a finer liion discharge curve.

Suggestions:
- All liion level to battery level values could be stored in a look up table

Closed 2025-02-03.

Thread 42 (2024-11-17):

Refactor the USB-PD negociation to include the OTG

BaptisteHudyma, 2024-11-17:
The current usd pd negociation only supports the sink option selection.

It should be refactored to :
- be similar to the standard usb-pd interface used in linux
- handle the source and sink types
- handle the mode swap functionality

BaptisteHudyma, 2025-02-24:
Handled by #68

Closed 2025-04-19.

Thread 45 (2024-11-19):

Refactor the change luminosity ramp

BaptisteHudyma, 2024-11-19:
The current luminosity ramp is linear, and the associated real luminosity is not.
An easing function should be integered to allow a finer choice of luminosities at low levels.

This change won't affect the indexable lamp type, because it's luminosity is already code based.

BaptisteHudyma, 2025-01-23:
implemented with the fix for #69

Closed 2025-01-23.

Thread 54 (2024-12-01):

Brief occasional flash of the strip when powering off

BaptisteHudyma, 2024-12-01:
This bug is visible when using the indexable lamp type.

When powering off, we can sometime notice a brief powerful white flash of the led strip.
This is due to the strip being handled in another thread, and being updated after the user code is disabled (concurency).

This can also be because the strip object is updated in user::power_off_sequence instead of the thread, and the power off is too late for this to be effective.

This bug is rare but very noticeable when it happens

BaptisteHudyma, 2025-01-17:
Identified: due to a thread race conditons.
For now, corrected using a set variable to lock the other threads after the shutdown order is emitted, just before effectivly shutting the led strip.

Closed 2025-01-17.

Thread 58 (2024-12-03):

Flickering on microphone effets

BaptisteHudyma, 2024-12-03:
The sound reactive animations are fickering noticibly.

This is because:
- the mic data is set on interrupts
- the animations are running on another thread
- The mic data is cleared on read

All those parameters interacting together produces the flickering effects in my opinion.

Potential fixes:
- Do not clear the data after reading (potential for data smearing)
- Keep the last value after computation on valid data and return it instead (again, potential data smearing)

Closed 2025-04-06.

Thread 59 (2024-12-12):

Implement short radio wave communication

BaptisteHudyma, 2024-12-12:
Our hardware supports 1Mbps, 2Mbps, Bluetooth, 802.15.4 (250kbps), and some Nordic proprietary modes.

If the device is not in Bluetooth, the same communication network can be used for IEEE 802.15.4 communication.

Less secure than Bluetooth, it give a possibility to do very low energy communication, with public key encryption (shared between all lamps), and a not so private key in the repo, that enable a safe (ish) low level communication between close lamps.

Ideally, we should implement a local Web network between close lamps.

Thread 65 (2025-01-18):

Refactor alert display

BaptisteHudyma, 2025-01-18:
Alert display is a pack of if else, that could benefit from being regrouped in a dedicated routine, using look up tables or templates implementations.

This refacto should come with the following:
- generic hysteresis function
- change the alert "battery reading incoherent to differentiate between battery too low (deep discharge or wrong battery) vs battery too high (wrong battery)
- a generic "alert_shutdown_is_timeout" that shutdown the system if an alert is not cleared before a certain time

BaptisteHudyma, 2025-02-24:
Resolved in #74

Closed 2025-02-24.

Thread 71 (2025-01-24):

Improve start up time

BaptisteHudyma, 2025-01-24:
The start time for the lamp should be <200ms (between user click & main light turning on).

- main program loading takes about 150ms, and for now cannot be reduced
- the behavior state machine spends some cycles on setups, it could skip looping is a state returns immediately
- parameter loading time is négligeable
- charging component turn on time is not measured yet

BaptisteHudyma, 2025-04-06:
resolved with the new bootloader, and the hot start code in the charge component

Closed 2025-04-06.

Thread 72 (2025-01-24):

End of charge states

BaptisteHudyma, 2025-01-24:
- a cable unplugged in charge mode should turn off the lamp under 1second
- the end of charge status should be locked when reached (battery 100% for 1min), and charge can start back when battery goes under 95% after 5min

Closed 2025-04-20.

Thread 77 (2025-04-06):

Add an alert for the USB port

BaptisteHudyma, 2025-04-06:
A visual alert should be raised, and block charge/OTG when the port protection sends an error signal.

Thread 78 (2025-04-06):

Throttle charge current with temperature

BaptisteHudyma, 2025-04-06:
The charge current should diminish when internal temperature is rising, to always stay in the safe zone.

The core and balancer temperature should both be handled

Closed 2025-04-06.

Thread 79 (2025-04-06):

Use individual battery voltage as voltage reference

BaptisteHudyma, 2025-04-06:
The pack voltage is used everywhere in the system.

The minimum cell voltage should be used to display autonomy, the maximum cell voltage should be checked when charging, to never go above the limit

Closed 2025-04-06.

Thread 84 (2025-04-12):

Add CC charge mode

BaptisteHudyma, 2025-04-12:
When the voltage reaches the battery target voltage, the charge process should not stop right away, but the charge current should go down.

Wait until the current drops below a low threshold (eg < 50mA) and the voltage is above the charged threshold to stop the charge.

Closed 2025-04-25.

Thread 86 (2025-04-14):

Monitor threads life

BaptisteHudyma, 2025-04-14:
The thread that uses the watchdog shall also watch the other thread life, using FreeRTOS task life function, and do something in case a thread is "blocked":

Options
- reset the device
- alert user
- shutdown
- All of the above ?

BaptisteHudyma, 2025-08-29:
Resolved by #211

Closed 2025-08-29.

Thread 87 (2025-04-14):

Handle inputs in separate thread

BaptisteHudyma, 2025-04-14:
All inputs, specially the main button, should never depend on custom user code.
A separate button thread shall be created.

Alternatively, the button logic can be handled fully on interrupts

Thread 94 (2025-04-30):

Handle balancer alerts

BaptisteHudyma, 2025-04-30:
- handle the battery balancing wire missing
- think about the wake signal integration
- handle individual celle under/overvoltage

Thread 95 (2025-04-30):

Add diode on external v33

BaptisteHudyma, 2025-04-30:
Add a diode on the v33 pinhole, so external power user cannot force 3.3 or other voilages on the inner circuit

Closed 2025-05-06.

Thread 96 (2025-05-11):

crash on PD state machine

BaptisteHudyma, 2025-05-11:
Power delivery in source mode (lamp as an external battery) can sometimes crash when the sink is disconnected

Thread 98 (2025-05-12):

Stop OTG after non use

BaptisteHudyma, 2025-05-12:
If the vbus current falls to near zero after some time in OTG mode, the OTG should stop to prevent useless battery usage

BaptisteHudyma, 2025-08-29:
Resolved by #225

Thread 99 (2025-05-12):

Identify the cause of the led flickering at low vbus voltage

BaptisteHudyma, 2025-05-12:
With the simple lamp type, when on low luminosity, the led flickers noticeably (not critical, but bothering)

Potential causes:
- not enough capacity on vbus: tested up to 220uF, no changes
- not enough capacity on vsys: tested up to 220 uF, no changes
- voltage loop unstable at low intensity: possible how to stabilize it ?

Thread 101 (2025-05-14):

Negotiate voltages close to battery

BaptisteHudyma, 2025-05-14:
Instead of getting the highest voltage like now, change the logic to negotiate a voltage close but above the battery level.
This will improve the charging efficiency.

Also, cut the negociation algorithm when not needed (battery full, lamp on, ...)

BaptisteHudyma, 2025-09-29:
Useless efforts !

Closed 2025-09-29.

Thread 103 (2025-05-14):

Investigate power source refusal

BaptisteHudyma, 2025-05-14:
On some boards, the program refuses to switch from sink to source.
Investigate and correct this.

Observations:
- The state machine bounces between the disconnect and disconnect debounce states.
- the board can negotiate high voltages without problems

Closed 2025-08-28.

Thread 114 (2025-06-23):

Add user input action system

BaptisteHudyma, 2025-06-23:
Add a system to register user events on inputs :
- button clicks
- button click and hold
- lamp tilt/shake

Modes can register on those events to make their own behaviors

deuxksix, 2025-07-31:
Custom clicks & click+hold behavior was the intended behavior behind `custom_hold` and `hasButtonCustomUI`

However, we need to decide how can users enable / disable that custom UI for a given mode — the WIP proposal was that users would be required to turn off the lamp, then turn it on again while holding the button / doing a 3H / something else.

Also, if you add a `imu_shake_default` and a `imu_tilt_default` to `indexable_behavior.hpp` I'll happily add all the required callbacks in the manager / modes for them to implement whatever they want with it :)

deuxksix, 2025-08-19:
These two (#195 #196) should do the trick. Added that to [1.1 milestone](https://github.com/BaptisteHudyma/Lamp-Da/milestone/1) as it would be a nice addition.

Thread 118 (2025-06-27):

Investigate power delivery stopping

BaptisteHudyma, 2025-06-27:
When using a power delivery with voltage greater than 9V, the lamp keeps feeding the voltage, but the target device (samsung phone) stops charging after some seconds.

Potential causes :
- vbus voltage is too far from USB standard deviation of voltage
- Missing acknowledge for high voltages
- ??

Closed 2025-08-28.

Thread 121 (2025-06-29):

Resolve led animation occasional flickering

BaptisteHudyma, 2025-06-29:
Most animations using fade blur or clear function could have a weird dlickering effect.

Solve it !

Closed 2025-06-30.

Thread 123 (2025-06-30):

Fix the delta time and timescale

BaptisteHudyma, 2025-06-30:
Add a delta time function in the manager to get the real delta time for animations.
Delta time should be the delta time between the last two frames

Fix the global delta time  of the user loop to run at a fix frequency.
The current implementation is not fixed update
FIX: move the loop runtime delay to the start of the user loop , to correct from the last loop run.

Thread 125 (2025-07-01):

Add a CLI lamp type indication

BaptisteHudyma, 2025-07-01:
Add a unique identifier per lamp type, that is accessible per the CLI.

This will be used for the automated update system.

The unique identifier should have a compulsion check to verify it's uniqueness.

If possible, add a check before pushing a new program to a lamp, that the lampe as no CLI (unprogramed) or is the correct lamp type. This will prevent a 5v strip version to be used with the 12v default

Closed 2025-09-03.

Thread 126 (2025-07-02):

Simplidy the global README

BaptisteHudyma, 2025-07-02:
Split the first README, most of it should be in a separate README for install/compile.

The current README is too much to read and start using the project

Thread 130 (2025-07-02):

Handle charge faults locked state

BaptisteHudyma, 2025-07-02:
When a charger fault is detected, the charger locks up in an error state to prevent further dangerous errors.

The error "ERROR SOFTWARE" should be more precise when debugging.
There should be a system to unlock this state.

Closed 2025-08-20.

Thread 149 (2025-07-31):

Use the same clang for simulator and the arduino

deuxksix, 2025-07-31:
When building simulator, if the arduino clang environment is set up, use it directly.

This will facilitate setup for users with older clang versions, thus relying on the "safe arduino install" and not their system clang.

Also, it should prevent us from using features that are available to system clang, but not present in arduino clang.

deuxksix, 2025-08-03:
This is not possible, arduino compiler is ARM only :)

Closed 2025-08-03.

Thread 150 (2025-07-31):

Migrate away from "legacy modes"

deuxksix, 2025-07-31:
Legacy modes directly use the "strip" object which prevent us to abstract away the hardware. An on-going goal of mine is to use `LampTy` as an unified interface to the hardware for the user, independently of which kind of mode they want to write.

Removing "direct strip access" from modes is also the required path to implement things like ramp animations, screen overlays, drawing functions with proper dithering, etc.

However, as most modes are for now still doing the `.getLegacyStrip()` direct access, new users are replicating this while writing new modes, and we're going to meme ourselves into a corner that will later break our users code & their custom modes.

To avoid that, we should take some time to migrate each legacy mode to its own file in `modes/default/<mode-name>.hpp` when appropriate (other modes accessing the hardware directly, as they do heavy access C-like hardware APIs, are less of priority and should wait for proper support in `LampTy` of their required feature, before migration)

--------------

This issue targets the "simple to migrate" legacy modes, another issue should follow for the IMU / sound FFT stuff.

deuxksix, 2025-08-19:
Breaking down which modes may be already started:

- [ ] `PolarMode` is ready to be migrated 💚
   - 🟢 has `modes::colors::from_palette` as drop-in replacement for `get_color_from_palette`
   - 💡 add `modes::utils::linear_scale` (with documentation) as `lmpd_map` with _static_ boundaries
- [ ] `SineMode` is ready to be migrated 💚
   - 🟢 has `modes::colors::from_palette` as drop-in replacement for `get_color_from_palette`
   - 💡 add `modes::colors::blend(leftColor, rightColor, blendAmount)` as `utils::color_blend` +simplify `b16`
   - ⚠️ using `colors::from_blend` to black may be replaced by `colors::fade`
- [ ] `DriftMode` is ready to be migrated 💚
   - 🟢 has `modes::colors::from_palette` as drop-in replacement for `get_color_from_palette`
   - 💡 add `modes::colors::add<useFastAdd>(leftColor, rightColor)` as `utils::color_add` +`LMBD_INLINE`
   - 💡 add `modes::colors::fade<isVideoMode>(inputColor, fadeAmount)` as `utils::color_fade` +`LMBD_INLINE`
   - 💡 add `modes::hardware::LampTy::blur(blueAmount)`
   - ⚠️ may be able to use `ctx.lamp.tick` to replace the `time_ms() / 32` usage
- [ ] `DistMode` is ready to be migrated 💚
   - ⚠️ maybe `utils::gamma8` can be migrated in a meaningful way
- [ ] `VuMeterMode` is ready to be migrated 💚
  - 🎉 likely you can have fun having a ramp to configure how "reactive" meter is
  - 💡 may also add a new `VuMeterTy` inside `modes::audio` to help build beautiful sound reactive modes
  - ⚠️ shall replace `GenerateGradientColor` with `modes::colors::PaletteGradient`+`modes::colors::from_palette`
- [ ] `RainbowSwirlMode` not ready ❌
  - 🟢 has `modes::colors::fromAngleHue` to replace `hue_to_rgb_sinus`
  - 🟡  WIP decide how to migrate `Color`+`animations::fill`
- [ ] `PartyFadeMode` not ready ❌
   - 🟢 has `modes::colors::from_palette` as drop-in replacement for `get_color_from_palette`
   - 🟡 WIP decide how to migrate `Color`+`animations::fade_in`
   - 💡 add `modes::colors::from_gradient(startColor, endColor, position)` to replace `utils::get_gradient`
   - ⚠️ probably may drop `GeneratePaletteIndexed` which only wraps `get_color_from_palette`
   - ⚠️ probably may be simplified in its behavior
- [ ] `ColorWipeMode` not ready ❌
  - 🟡  WIP decide how to migrate `Color`+`animations::color_wipe_up`+`animations::color_wipe_down`
  - ⚠️ probably may drop `GenerateComplementaryColor` for simplicity
- [ ] `RandomFillMode` not ready ❌
  - 🟡  WIP decide how to migrate `Color`+`animations::double_side_fill`
  - ⚠️ probably may drop `GenerateRandomColor` for simplicity
- [ ] `PingPongMode` not ready ❌
  - 🟡  WIP decide how to migrate `Color`+`animations::dot_ping_pong`
  - ⚠️ probably may drop `GenerateComplementaryColor` for simplicity
- [ ] `NoiseMode` not ready ❌
   - 🔴 need to clarify how strip buffers may be accessed by user modes
- [ ] `FftMode`  not ready ❌
   - 🔴 need to clarify how microphone FFT may be accessed by user modes
   - 🔴 need to clarify how strip buffers may be accessed by user modes
- [ ] `LiquideMode` not ready ❌
   - 🔴 need to clarify how IMU may be accessed by user modes
   - ⚠️ may drop `GenerateRainbowSwirl` and use static `modes::colors::PaletteTy` color palettes
- [ ] `LiquideRainMode` not ready ❌
   - 🔴 need to clarify how IMU may be accessed by user modes
   - ⚠️ may drop `GenerateRainbowSwirl` and use static `modes::colors::PaletteTy` color palettes

deuxksix, 2025-08-19:
Important side-note:
- all drawing functions / animations speed shall be configured using milliseconds (how much time to completion, etc)
- whenever possible, do not use locally defined ever-increasing counters, prefer only using `ctx.lamp.tick` which is guaranteed to be increased at a constant rate each second (and thus can easily converted to a millisecond amount)

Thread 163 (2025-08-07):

Make mr_proper fails when the directory does not have the correct name

epsln, 2025-08-07:
When using

`make mr_proper arduino-cli-download safe-install`

After cloning the repo without renaming it `LampColorControler`, will fail in obscure manner:

```
 --- has-board-installed
Can't open sketch: main file missing from sketch: /home/epsilon/dev/Lamp-Da/Lamp-Da.ino
Can't open sketch: main file missing from sketch: /home/epsilon/dev/Lamp-Da/Lamp-Da.ino
Can't open sketch: main file missing from sketch: /home/epsilon/dev/Lamp-Da/Lamp-Da.ino
Can't open sketch: main file missing from sketch: /home/epsilon/dev/Lamp-Da/Lamp-Da.ino
Can't open sketch: main file missing from sketch: /home/epsilon/dev/Lamp-Da/Lamp-Da.ino
Can't open sketch: main file missing from sketch: /home/epsilon/dev/Lamp-Da/Lamp-Da.ino
Can't open sketch: main file missing from sketch: /home/epsilon/dev/Lamp-Da/Lamp-Da.ino
Can't open sketch: main file missing from sketch: /home/epsilon/dev/Lamp-Da/Lamp-Da.ino
 --- check-compiler-cmd
/bin/bash: line 2: --version: command not found

ERROR: compiler "" seems to be inappropriate?

Troubleshooting:
 - detected compiler path is ""
 - detected compiler command is ""
 - output of " --version" below:

/bin/bash: line 11: --version: command not found
 - expected "Arm Embedded Processors" in compiler version string
 - packages like "libc6-dev-i386" or "lib32-glibc" may be needed locally for 32-bit support
 - packages like "gcc-arm-none-eabi" or "arm-none-eabi-gcc" may be needed locally for ARM support
 - you can also try "make mr_proper safe-install" (may take 1.4 gigabyte of space)

make[2]: *** [Makefile:152: check-compiler-cmd] Error 1
make[2]: Leaving directory '/home/epsilon/dev/Lamp-Da'
make[1]: *** [Makefile:172: /home/epsilon/dev/Lamp-Da/_build/.deps-ok] Error 2
make[1]: Leaving directory '/home/epsilon/dev/Lamp-Da'
make: *** [Makefile:269: safe-install] Error 2
```

The fix is renaming the directory (or just reading the instructions and cloning it correctly), but it would be better to output an helpful message reminding the user to do so :)

Closed 2025-08-08.

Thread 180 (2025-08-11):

Implement BanLanX bluetooth service

BaptisteHudyma, 2025-08-11:
Create an inherited class to BLEService, that implement every parameters to be used with the BalanX app.

It should appear as a compatible device on the app, and switch the lamp to a special display mode, fully controled by the app, when connected.

Ressources :
- [BLE assigned uiid](https://www.bluetooth.com/wp-content/uploads/Files/Specification/HTML/Assigned_Numbers/out/en/Assigned_Numbers.pdf)
- [Adafruit color service](https://github.com/adafruit/Adafruit_nRF52_Arduino/blob/master/libraries/BLEAdafruitService/src/services/BLEAdafruitColor.cpp)
- [Adafruit UART service](https://github.com/adafruit/Adafruit_nRF52_Arduino/blob/master/libraries/Bluefruit52Lib/src/services/BLEUart.h)

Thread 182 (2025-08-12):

Refactor button input system

BaptisteHudyma, 2025-08-12:
The button should be handled with interrupts and timers only, to be decoupled from the user thread:
- button clicks callbacks should be irc calls on a queue
- button ramps and time checks should be on system timers

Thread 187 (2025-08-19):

Migrate PulseMode

deuxksix, 2025-08-19:
- [ ] `PolarMode` is ready to be migrated 💚
   - 🟢 has `modes::colors::from_palette` as drop-in replacement for `get_color_from_palette`
   - 💡 add `modes::tools::linear_scale` (with documentation) as `lmpd_map` with _static_ boundaries

On the second item, don't be afraid of using `LMBD_INLINE` or using template arguments to have static boundaries 👍

Closed 2025-09-10.

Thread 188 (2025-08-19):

Migrate SineMode

deuxksix, 2025-08-19:
- [ ] `SineMode` is ready to be migrated 💚
   - 🟢 has `modes::colors::from_palette` as drop-in replacement for `get_color_from_palette`
   - 💡 add `modes::colors::blend(leftColor, rightColor, blendAmount)` as `utils::color_blend` +simplify `b16`
   - ⚠️ using `colors::from_blend` to black may be replaced by `colors::fade`

You can also complete the following:
   - 💡 add `modes::colors::fade<isVideoMode>(inputColor, fadeAmount)` as `utils::color_fade` +`LMBD_INLINE`

Note that both new blend / fade function may be simplified by using directly floats 👍

(but maybe if you're not up to do some benchmarks, default to copy-pasting previously existing cod)

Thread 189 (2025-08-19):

Migrate DriftMode

deuxksix, 2025-08-19:
- [ ] `DriftMode` is ready to be migrated 💚
   - 🟢 has `modes::colors::from_palette` as drop-in replacement for `get_color_from_palette`
   - 💡 add `modes::colors::add<useFastAdd>(leftColor, rightColor)` as `utils::color_add` +`LMBD_INLINE`
   - 💡 add `modes::colors::fade<isVideoMode>(inputColor, fadeAmount)` as `utils::color_fade` +`LMBD_INLINE`
   - 💡 add `modes::hardware::LampTy::blur(blueAmount)`
   - ⚠️ may be able to use `ctx.lamp.tick` to replace the `time_ms() / 32` usage

Feel free to improve the blur implementation, if you're up to getting your hands dirty 🙂

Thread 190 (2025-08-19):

Migrate DistMode

deuxksix, 2025-08-19:
- [ ] `DistMode` is ready to be migrated 💚
   - ⚠️ maybe `utils::gamma8` can be migrated in a meaningful way

There are a lot of `-8` and `-16` tools that we're going to keep using in many places, what we care here is to have things such as `gamma8` that rely on huge tables, defined `static constexpr` in a global header in proper `std::array` containers, but it doesn't matter exactly where they are.

Feel free to migrate `utils::gamma8` to `modes::colors` or `modes::tools` if you find it meaningful, for example 👍

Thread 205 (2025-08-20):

Simulator for indexable has a misalignment

deuxksix, 2025-08-20:
Simulator assumes that each row shift LEDs by half exactly, but recently build hardware highlights it shifts more like by 0.541151 units only.

This creates a half-led misalignment every 12.150373 rows, almost invisible usually, except when you are drawing straight lines.

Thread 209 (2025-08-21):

Optimize sleep current consumption

BaptisteHudyma, 2025-08-21:
Using a test circuit, optimize the sleep mode current consumption to prevent battery being killed.

Software version 1.1 is expected to last a year in sleep mode, but the system should be able to last for a longer time in sleep mode.
-[Nordik notes on current consumption](https://docs.nordicsemi.com/bundle/ps_nrf52840/page/chapters/current_consumption/doc/frontpage.html)
- [check issue on adafruit_nrf52_arduino](https://github.com/adafruit/Adafruit_nRF52_Arduino/issues/165)

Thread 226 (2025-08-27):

Resolve charge negociation bug

BaptisteHudyma, 2025-08-27:
Reproduce :
- plug fast charge compatible charger
- wait until power is negociated (breeeze animation)
- start lamp
- slow charge alert (normal)
- turn off system
- go back to charge mode

At the last step, the system stays in slow charge mode, but everything is ok to charge.

-> Seems to come from the fact that the state machine never catches the new negociation events after a suspend.
Tried to reset it, force hard reset, it works but no new voltage is negociated.
Not on master : only on the #225

Closed 2025-08-28.

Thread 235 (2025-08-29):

Investigate power switch refusal on start

BaptisteHudyma, 2025-08-29:
On some lamps, the power switch option is not displayed on the connected usb device and the user cannot switch power.
The state machine seems to miss the first PD message and go to legacy charge mode, missing the signal.

Closed 2025-09-04.

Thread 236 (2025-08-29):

Occasional brief  system in error state when disconnecting usbc cable

BaptisteHudyma, 2025-08-29:
When in chargin, when unplugging or swapping to sink from source, the system error can appear for 2 seconds before the lamp shuts down.

This is due to a power gate alert, because the vbus line does not clear fast enough below 4V.

Closed 2025-08-29.

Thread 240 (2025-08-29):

Software error on usbc unplug

BaptisteHudyma, 2025-08-29:
There is a rare bug, when a software error is raised when the usb cable is unplugged.

It emanates from the charge_ic file, so there is only one place where is can be raised (register write).

Closed 2025-08-29.

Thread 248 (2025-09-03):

Investigate new crash

BaptisteHudyma, 2025-09-03:
User reported a crash after a long time with the indexable lamp at high brightness, and noticed that the battery was low when turning it on again.

-> could it be that the emergency shutdown misses a critical sleep instruction ?
-> could the thread interruption in the middle of an i2c operation cause a lockup ?
-> could the deactivation of the 3.v ext rail causes a component to shutdown and i2c to hang forever ?

BaptisteHudyma, 2025-09-04:
Tried to fix it in #250

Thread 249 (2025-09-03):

Use an i2c dedicated task to have timeout

BaptisteHudyma, 2025-09-03:
For now, the i2c can hang forever in case of no answer.
We should find a way to prevent this by adding a timeout.

An i2c task could be created, that locks the calling task with a timeout event, and run in parallel to it. If it succeeds, it unlocks it with the correct flag.

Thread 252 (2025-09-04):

Resolve custom ramp disappearing

BaptisteHudyma, 2025-09-04:
Custom ramp (3H) are not displayed after a group switch.

On 1.3 and less

EG:
- go to a mode with a custom ramp
- activate the ramp (3H)
- ramp is visible
- switch categories (3C) until we go back to the ramp mode
- activate the ramp (3H)
- **ramp is not visible** -> it should be !

It appears that changing categories breaks the ramp display logic

Should be resolved by #57

Closed 2025-09-07.

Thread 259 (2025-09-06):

Resolve occasional button locked state

BaptisteHudyma, 2025-09-06:
On some case, the button cab stay locked in pressed position in software.

This may be due to an interrupts behing miss read.

Fix:
Check on the button loop that the pressed state is coherent, and force call interrupts if not the case

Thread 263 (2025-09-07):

Button short flash on charger plugged

BaptisteHudyma, 2025-09-07:
When plugging a charger into the system, the button has a short visible flash of a color close to battery color

Fix:
Start the slow charge animation by black instead of the target color ?

Closed 2025-09-07.

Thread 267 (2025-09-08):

Add readme for DFU update

BaptisteHudyma, 2025-09-08:
Add a doc page to explain the DFU update process :
- plug the lamp to a computer/phone
- open a serial port at 115200 bauds
- test the connection by sending "v" to get system version, and "type" to get lamp type
- type "DFU" to enter device firmware update
- The lamp reboots and appears as a mass storage device
- Put the .utf2 file corresponding to you lamp type into the mass storage device
- touch nothing !
- The lamp reboots with the updated firmware

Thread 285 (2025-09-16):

First bluetooth activation is always a crash

BaptisteHudyma, 2025-09-16:
When calling for the first time the bluetooth advertising (4H from off), the lamp always crashes.
It never happens again after that

BaptisteHudyma, 2025-09-21:
This bugs happens only once, and never again (even after a board hard reset).
It appears to be impossible to correct right now

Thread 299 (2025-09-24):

Add lockout mode

BaptisteHudyma, 2025-09-24:
Say it with me now: LIKE IN ANDURIL, add a the lockout mode:
- 4C from off activates the lockout mode, the lamp do not start with anything else than 3C or more

thoughts on this:
More difficult that it appears. The lamp in shutdown state is waken up by any interrupt on button or vbus (usb)
Need to integrate a parameter flag for lockout mode, cleared on wake up.
If woken up from button interrupt and flag is set, go back to sleep immediately

I dont like this, as a mistake can lock the lamp in shutdown state forever.

It could also be a main machine state (lockout state), where the only transition is >3C. The problem with this is that user can forget the lamp in lockout state and it discharges faster

Closed 2025-09-25.

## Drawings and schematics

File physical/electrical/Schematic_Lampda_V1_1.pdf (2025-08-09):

## USBC power switch (5A max)

## liion charger (5 to 20v in) 6A max

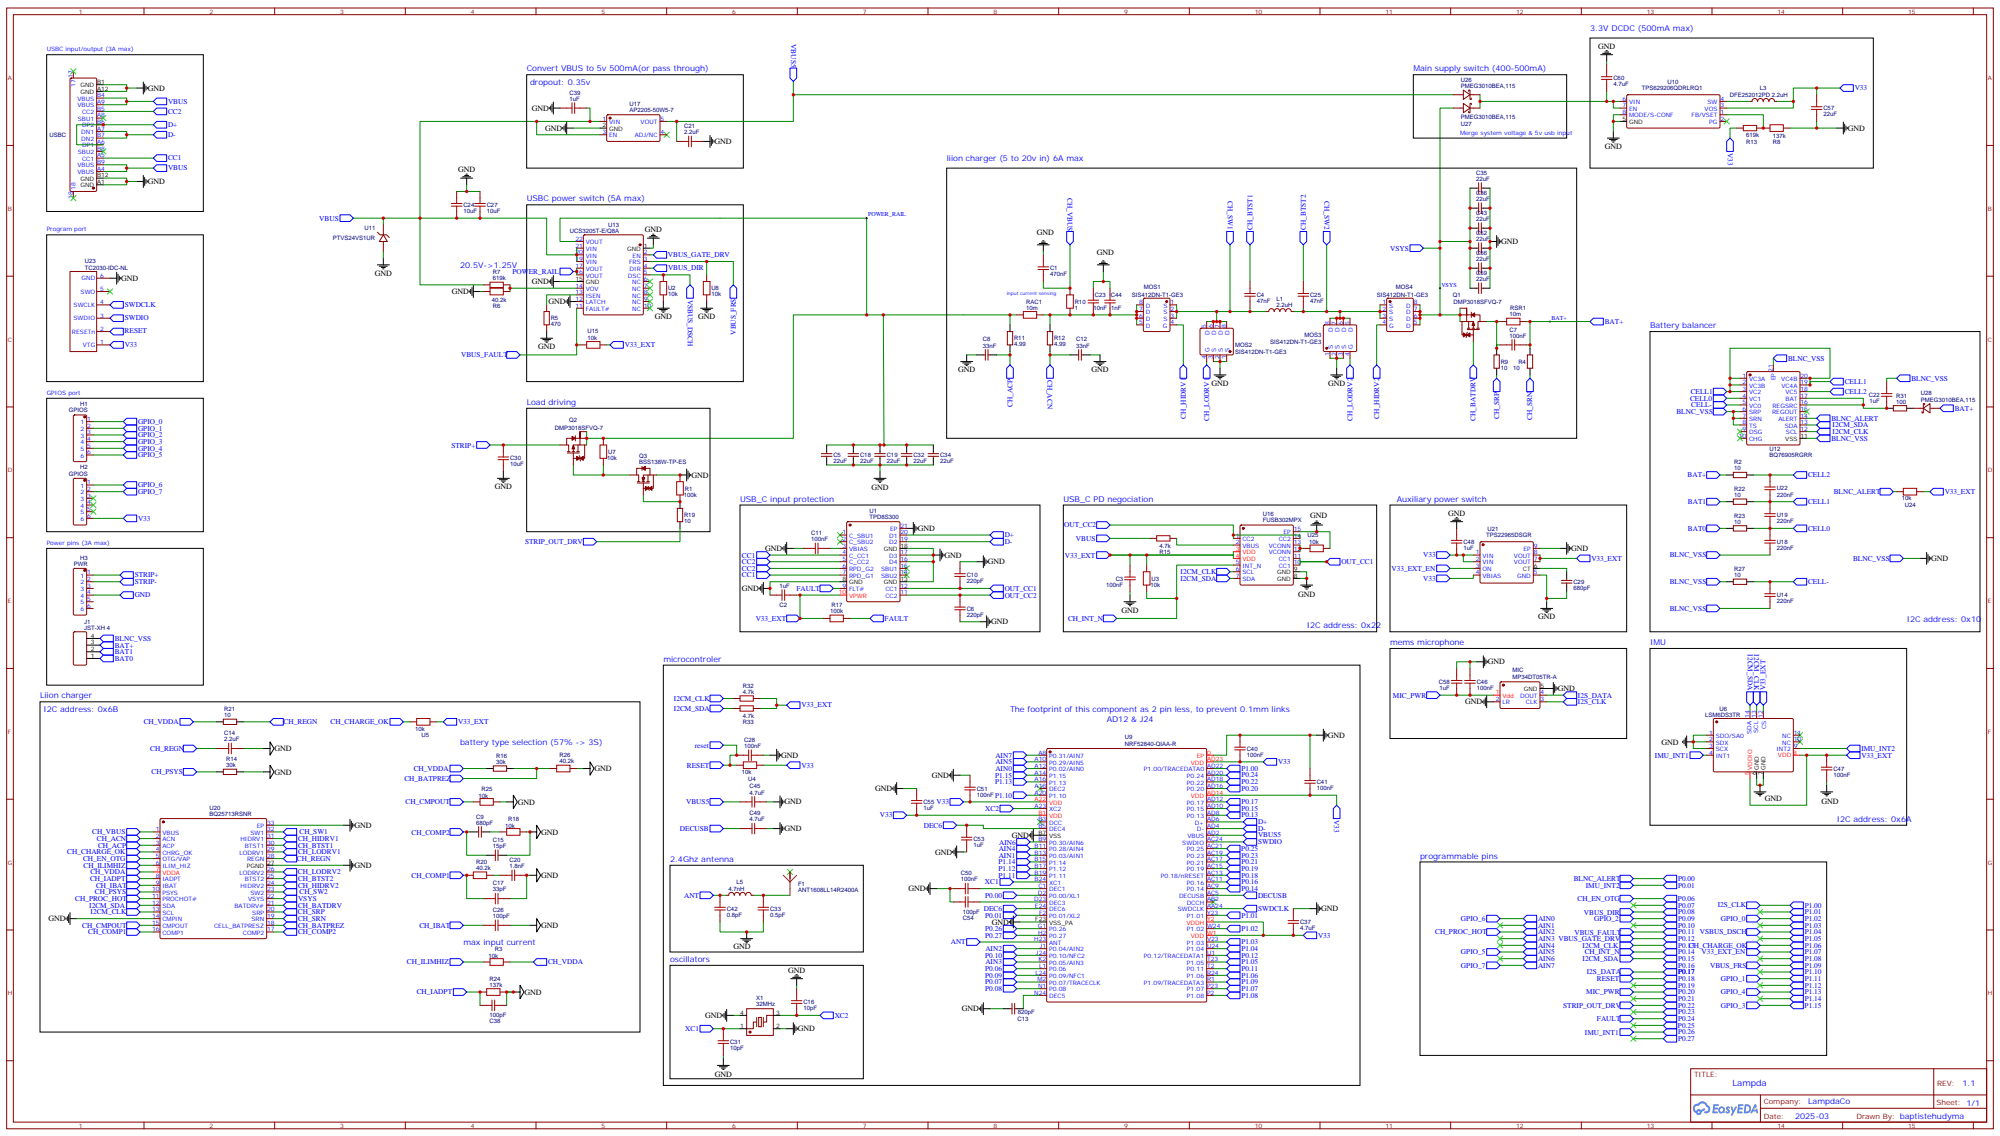
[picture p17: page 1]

USBC input/output (3A max)
GND A1 GND B12 VBUS A4 VBUS B9 CC1 A5 SBU2 B8 DP1 A6 DN2 B7 DN1 A7 DP2 B6 SBU1 A8 CC2 B5 VBUS A9 VBUS B4 GND A12 GND B1

Convert VBUS to 5v 500mA(or pass through)
dropout: 0.35v

UCS3205T-E/Q8A
NC 10 FAULT# 11 LATCH 12 ISEN 13 VOV 14 GND 15 VOUT 16 VOUT 17 VIN 19 VIN 20 VIN 21 VOUT 22

The footprint of this component as 2 pin less, to prevent 0.1mm links

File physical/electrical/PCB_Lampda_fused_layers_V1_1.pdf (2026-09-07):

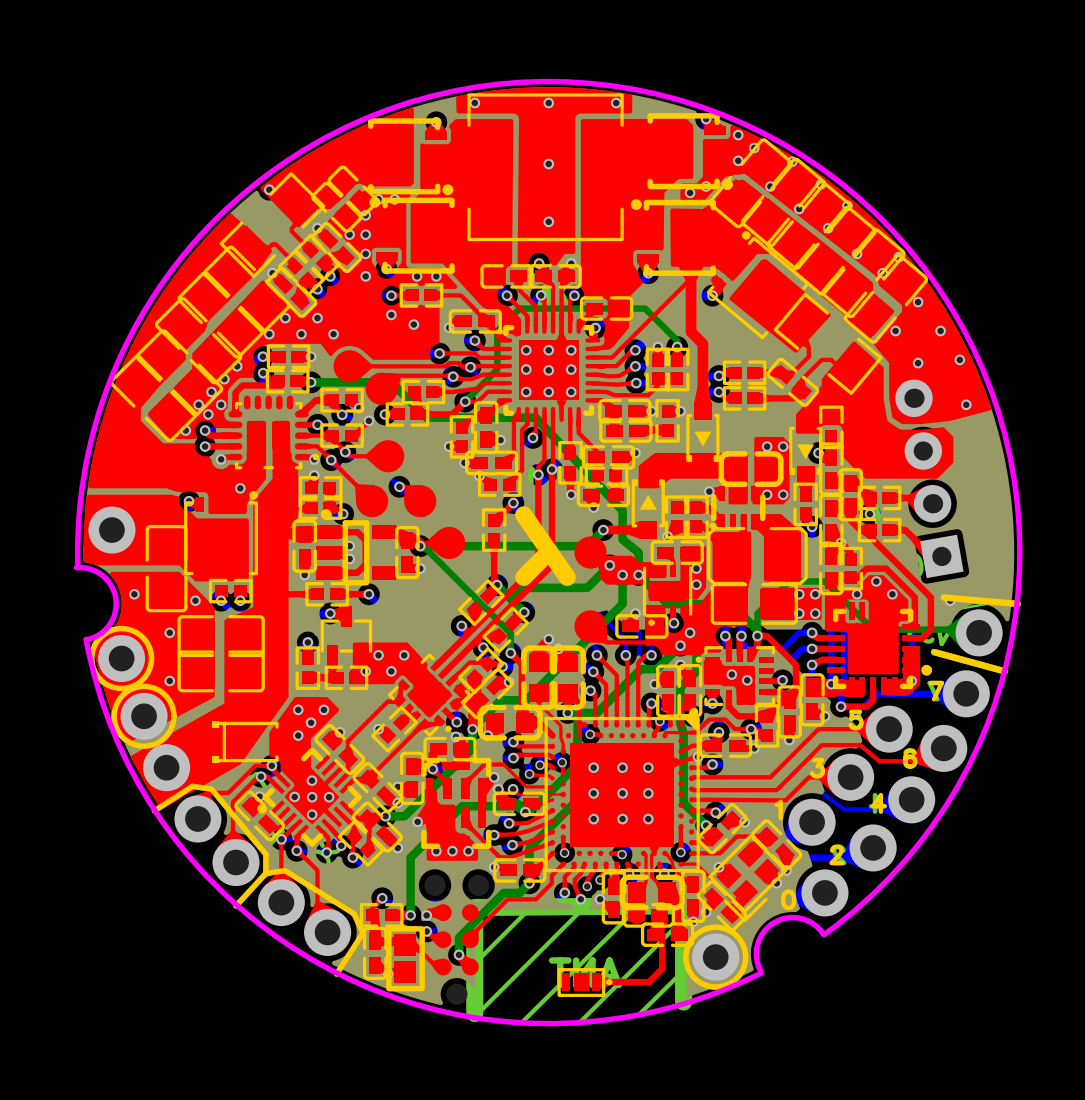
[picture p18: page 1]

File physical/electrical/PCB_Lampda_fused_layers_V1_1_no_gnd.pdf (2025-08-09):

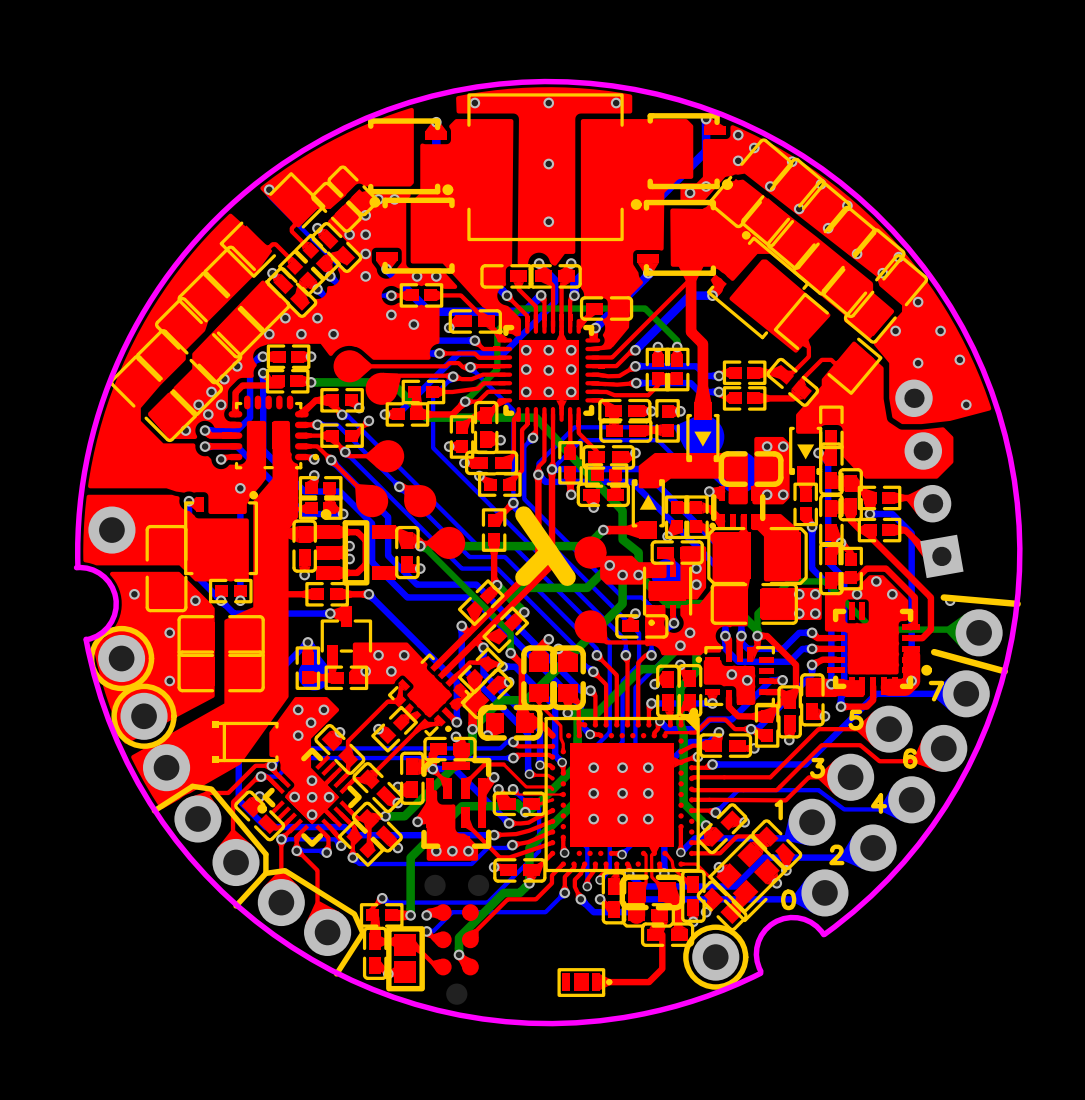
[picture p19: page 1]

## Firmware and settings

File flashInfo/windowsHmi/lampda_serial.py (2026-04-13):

import time
import serial
import serial.tools.list_ports
import requests
import shutil
import os
import re, subprocess

#read usb devices
import sys, platform

try:
    import win32file
except ImportError:
    win32file = None

# used to translate text strings
import TextLangage as tx

## Store a release and all associated details
class Release:
    ## Constructor
    def __init__(self, api_response):
        r = api_response
        self.tag = r.get("tag_name")    ## Name of the tag
        self.name = r.get("name")       ## revision
        self.creation_date = r.get("created_at")    ## Create date
        self.updated_date = r.get("updated_at")     ## Update date
        self.published_date = r.get("published_at") ## Published date
        self.asset_url = [asset["browser_download_url"] for asset in r.get("assets", [])]   ## URL of the download
        self.description = r.get("body")    ## Body of the request, in JSON

## Store a lamp reference
class LampDa:
    ## Constructor
    def __init__(self):
        ## signal a board without a program
        self.type = "unflashed"

        self.hardware_v = ""    ## Version of the hardware
        self.firmware_v = ""    ## Version of the firmware
        self.base_v = ""        ## Base firmware version
        self.user_v = ""        ## Version of the user layer

## Update a device from a linux based ssystem
def update_devices_linux(label):
    devices = []
    # detect all parameters
    device_re = re.compile(r"(\S+)\s+(\S+)\s+(\S+)\s+(\S+)\s+(\S+)\s*(\S*)+\s*(\S*)\s*(\S*)", re.I)
    df = subprocess.check_output(['lsblk', '-f'])
    id_list = ["NAME", "FSTYPE", "FSVER", "LABEL", "UUID", "FSAVAIL", "FSUSE%", "MOUNTPOINTS"]
    for i in df.split(b'\n'):
        if i:
            info = device_re.match(i.decode('utf-8'))
            if info:
                dinfo = dict(zip(id_list, info.group(1,2,3,4,5,6,7,8)))
                # dinfo['device'] = '/dev/bus/usb/%s/%s' % (dinfo.pop('bus'), dinfo.pop('device'))
                devices.append(dinfo)

    # keep only the lamps
    final_devices = []
    for device in devices:
        if label in device['LABEL']:
            # check if we can mount it
            if device['MOUNTPOINTS'] == '':
                df = subprocess.check_output(["udisksctl", "mount", "-b", "/dev/"+device['NAME']])
                splitted = df.strip().split(b' ')
                device['MOUNTPOINTS'] = splitted[-1].decode('utf-8')

            if device['MOUNTPOINTS'] != '':
                final_devices.append(device['MOUNTPOINTS'])
                # we only care about one lamp anyway
                break;
    return final_devices

## Update the detected devices
def update_device_windows(label):
    import psutil
    for part in psutil.disk_partitions(all=False):
        try:
            psutil.disk_usage(part.mountpoint)  # test si accessible
            # Récupérer le volume label via Windows
            import ctypes

            vol_name_buf = ctypes.create_unicode_buffer(1024)
            fs_name_buf = ctypes.create_unicode_buffer(1024)
            serial = ctypes.c_uint32()
            max_component_len = ctypes.c_uint32()
            file_sys_flags = ctypes.c_uint32()

            ctypes.windll.kernel32.GetVolumeInformationW(
                ctypes.c_wchar_p(part.device),
                vol_name_buf,
                ctypes.sizeof(vol_name_buf),
                ctypes.byref(serial),
                ctypes.byref(max_component_len),
                ctypes.byref(file_sys_flags),
                fs_name_buf,
                ctypes.sizeof(fs_name_buf),
            )
            print("Lampda module name on windows", vol_name_buf.value)
            if vol_name_buf.value == label:
                return part.mountpoint
        except Exception:
            continue

## Search a target drive from a target label
def find_drive_by_label(label="LMBDROOT"):
    try:
        import platform
        system = platform.system()
        if system == 'Windows':
            return update_device_windows(label)
        else:
            devices = update_devices_linux(label)
            if(len(devices) > 0):
                print("Lampda module name on Linux", devices[0])
                return devices[0]

    except Exception as e:
        print("Could not check drives: ", e)

## Try to find all connected lamps
def find_lampda(sublist=None):
    lampdas = []
    text = "Lamp-da"
    search_list = (
        [p.device for p in serial.tools.list_ports.comports()]
        if sublist is None
        else sublist
    )
    if sublist != []:
        for port in search_list:
            try:
                with serial.Serial(port, baudrate=115200, timeout=0.1, write_timeout=0.2) as ser:
                    ser.write(("h" + "\n").encode())
                    response = ser.readline().decode(errors="ignore").strip()
                    if text in response:
                        lampdas.append((port, get_lampda_version(ser)))

            except Exception as e:
                print("Port search Exception", e)

    drive = find_drive_by_label()
    if drive is not None:
        lampdas.append((drive, LampDa()))

    return lampdas

## Parse the lamp to extract the versions
def get_lampda_version(ser):
    """search all version in the lampda"""
    info = {
        "hardware": None,
        "firmware": None,
        "base software": None,
        "user software": None,
        "type": None,
    }

    ser.write(("v\n").encode())

    data = True
    while data:
        try:
            data = ser.readline().decode(errors="ignore").strip()
            if data:
                for key in info.keys():
                    if key in data:
                        try:
                            info[key] = "v" + data.split(":")[-1]
                        except:
                            raise Exception(f"wrong formate data for {key} : {data}")
        except Exception as e:
            print(f"\n[Erreur lecture] {e}")
            break

    ser.write(("t\n").encode())

    data = True
    while data:
        try:
            data = ser.readline().decode(errors="ignore").strip()
            if data:
                if "unknown" in data:
                    info["type"] = "unknown"
                else:
                    info["type"] = data.split(" ")[-1]
            data = None

        except Exception as e:
            print(f"\n[Erreur lecture] {e}")
            break

    lampd = LampDa
    lampd.hardware_v = info["hardware"]
    lampd.firmware_v = info["firmware"]
    lampd.base_v = info["base software"]
    lampd.user_v = info["user software"]
    lampd.type = info["type"]

    return lampd

## Parse github to find the latest releases
def get_releases(url="https://api.github.com/repos/BaptisteHudyma/Lamp-Da/releases"):
    response = requests.get("https://api.github.com/rate_limit")
    if response.status_code == 200:
        rate_limit_data = response.json()["rate"]

        # keep a bit of margin
        if rate_limit_data['remaining'] > 10:
            response = requests.get(url)
            response.raise_for_status()  # lève une erreur si problème réseau ou API
            releases = response.json()
            return [Release(r) for r in releases]

    return []

## sort all releases version passed on argument and return the higher version number
def get_most_recent_version(releases: list[Release]):
    releases.sort(key=compare_version, reverse=True)
    return releases[0]

## return a value that correspond to a version number xwrote as vx.y.z with max 7 digit
def compare_version(version: Release):
    base_puissance = 1000000
    ret = 0
    for i, c in enumerate(version.tag):
        val = 0
        try:
            val = int(c)
        except:
            continue
        ret += val * base_puissance
        base_puissance /= 2
    return ret

## Send a reset command to the lamp
def resetLampda(ser):
    DFU_COMMAND = b"DFU\n"
    ser.write(DFU_COMMAND)

## Flash the lamp with a new release
def flash_lampda(port, lampda:LampDa, asset=None, local=False, skip_reset=False):
    if not skip_reset:
        try:
            with serial.Serial(port, baudrate=115200, timeout=0.1, write_timeout=0.2) as ser:
                resetLampda(ser)
        except Exception as e:
            raise e
        time.sleep(5)

    disk = find_drive_by_label()
    if disk == None:
        raise Exception(tx.get_text_translation(tx.USB_DRIVE_NOT_FOUND_ID))
    else:
        if local:
            file_to_flash = asset[0]
        else:
            uf2 = [file for file in asset if lampda.type in file]
            if len(uf2) != 1:
                raise Exception("Too much files were found")
            else:
                file_to_flash = lampda.type + ".uf2"
                download_release(uf2[0], file_to_flash)
        try:
            print("flashing ", file_to_flash, " to ", disk)
            shutil.copy(file_to_flash, os.path.join(disk, os.path.basename(file_to_flash).split('/')[-1]))
        except Exception as e:
            print("Exeption while flashing !", e)
            disk = find_drive_by_label()
            if disk is not None:
                raise e

## download the file {http_path] as {file_name}
def download_release(http_path, file_name):
    response = requests.get("https://api.github.com/rate_limit")
    if response.status_code == 200:
        rate_limit_data = response.json()["rate"]

        # keep a bit of margin
        if rate_limit_data['remaining'] > 10:
            response = requests.get(http_path)

            with open(file_name, "wb") as f:
                f.write(response.content)
                return
    raise Exception("Download limit exeeded")


if __name__ == "__main__":
    pass

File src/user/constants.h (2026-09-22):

/*! \file constants.h
    \brief User defined constants, relative to specific lamp types.
*/

#ifndef USER_CONSTANTS_H
#define USER_CONSTANTS_H

#include <cstdint>
#include <cmath>

namespace lampda {

//
// common to all lamp type
//

// does button usermode defaults to "lockdown" mode?
static constexpr bool usermodeDefaultsToLockdown = false;

static constexpr float c_PI = 3.1415926535897f;      ///< PI constant
static constexpr float c_TWO_PI = 6.2831853071795f;  ///< 2*PI constant
static constexpr float c_HALF_PI = 1.5707963267948f; ///< PI/2 constant

static constexpr float c_degreesToRadians = c_PI / 180.0f; ///< convert degrees to radians
// Update when the soft changes version
static constexpr uint8_t USER_SOFTWARE_VERSION_MAJOR = 1;
static constexpr uint8_t USER_SOFTWARE_VERSION_MINOR = 9;

//
// simple lamp type
//

#ifdef LMBD_LAMP_TYPE__SIMPLE

// compute the expected average loop runtime (in ms)
// defined as milliseconds / FPS
static constexpr uint32_t MAIN_LOOP_UPDATE_PERIOD_MS = static_cast<uint32_t>(1000 / 80.0f);

// parameters of the led strip used
static constexpr float consWattByMeter = 12;               // power consumption (in Watt/meters)
static constexpr uint16_t stripInputMinVoltage_mV = 9400;  // min allowed voltage
static constexpr uint16_t stripInputMaxVoltage_mV = 12000; // max allowed voltage
static constexpr float ledStripLength_mm = 91.0f * 25.0f;  // 91 sections of 25 mm

// define position of led 0 to the circuit center
static constexpr float circuitToLedZeroRotationX_degrees = 0.0f;
static constexpr float circuitToLedZeroRotationY_degrees = 0.0f;
static constexpr float circuitToLedZeroRotationZ_degrees = 88.0f;

#endif // LMBD_LAMP_TYPE__SIMPLE

//
// cct lamp type
//

#ifdef LMBD_LAMP_TYPE__CCT

// compute the expected average loop runtime (in ms)
// defined as milliseconds / FPS
static constexpr uint32_t MAIN_LOOP_UPDATE_PERIOD_MS = static_cast<uint32_t>(1000 / 80.0f);

// parameters of the led strip used
static constexpr float consWattByMeter = 10;               // power consumption (in Watt/meters)
static constexpr uint16_t stripInputMinVoltage_mV = 9000;  // min allowed led voltage
static constexpr uint16_t stripInputMaxVoltage_mV = 12000; // min allowed led voltage
static constexpr float ledStripLength_mm = 67.0f * 27.0f;  // 67 sections of 27 mm

// define position of led 0 to the circuit center
static constexpr float circuitToLedZeroRotationX_degrees = 0.0f;
static constexpr float circuitToLedZeroRotationY_degrees = 0.0f;
static constexpr float circuitToLedZeroRotationZ_degrees = 88.0f;

#endif // LMBD_LAMP_TYPE__CCT

//
// indexable lamp type
//

#ifdef LMBD_LAMP_TYPE__INDEXABLE
static constexpr float lampBodyRadius_mm = 25; // external radius of the lamp body

// parameters of the led strip used
#ifdef LMBD_LAMP_TYPE__INDEXABLE_IS_HD
// hd 240L/m strip
static constexpr uint16_t LED_COUNT = 870;                 // How many indexable leds are attached to the controler
static constexpr float consWattByMeter = 5;                // power consumption (in Watt/meters)
static constexpr uint16_t stripInputMinVoltage_mV = 12000; // min allowed voltage
static constexpr uint16_t stripInputMaxVoltage_mV = 12000; // max allowed voltage
static constexpr float ledByMeter = 244;                   // the REAL indexable led by meters (for a 240Led/m)
static constexpr float ledStripWidth_mm = 5.2f;            // width of the led strip
static constexpr float ledStripHeigh_mm = 0.7f;            // heigh of the led strip (calibrated for this strip)
static constexpr uint8_t minimumAllowedBrightness_8 = 3;   // minium allowed brightnes level,0-255

// compute the expected average loop runtime (in ms)
// defined as milliseconds / FPS
static constexpr uint32_t MAIN_LOOP_UPDATE_PERIOD_MS = static_cast<uint32_t>(1000 / 40.0f);
#else
// standard 160L/m strip
static constexpr uint16_t LED_COUNT = 580;                 // How many indexable leds are attached to the controler
static constexpr float consWattByMeter = 5;                // power consumption (in Watt/meters)
static constexpr uint16_t stripInputMinVoltage_mV = 12000; // min allowed voltage
static constexpr uint16_t stripInputMaxVoltage_mV = 12000; // max allowed voltage
static constexpr float ledByMeter = 162.6f;                // the REAL indexable led by meters (for a 160Led/m)
static constexpr float ledStripWidth_mm = 5.2f;            // width of the led strip
static constexpr float ledStripHeigh_mm = 0.7f;            // heigh of the led strip (calibrated for this strip)
static constexpr uint8_t minimumAllowedBrightness_8 = 3;   // minium allowed brightnes level,0-255

// compute the expected average loop runtime (in ms)
// defined as milliseconds / FPS
static constexpr uint32_t MAIN_LOOP_UPDATE_PERIOD_MS = static_cast<uint32_t>(1000 / 80.0f);
#endif
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

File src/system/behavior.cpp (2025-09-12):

#include "behavior.h"

#include <cstdint>

#include "src/system/ext/math8.h"
#include "src/system/ext/noise.h"

#include "src/system/alerts.h"

#include "src/system/power/charger.h"
#include "src/system/power/power_handler.h"
#include "src/system/power/power_gates.h"

#include "src/system/physical/battery.h"
#include "src/system/physical/button.h"
#include "src/system/physical/indicator.h"
#include "src/system/physical/fileSystem.h"
#include "src/system/physical/imu.h"
#include "src/system/physical/output_power.h"
#include "src/system/physical/sound.h"

#include "src/system/utils/colorspace.h"
#include "src/system/utils/constants.h"
#include "src/system/utils/utils.h"
#include "src/system/utils/state_machine.h"
#include "src/system/utils/input_output.h"
#include "src/system/utils/brightness_handle.h"
#include "src/system/utils/time_utils.h"

#include "src/system/platform/bluetooth.h"
#include "src/system/platform/time.h"
#include "src/system/platform/gpio.h"
#include "src/system/platform/i2c.h"
#include "src/system/platform/registers.h"
#include "src/system/platform/threads.h"
#include "src/system/platform/print.h"

#include "src/user/functions.h"

namespace behavior {

static constexpr uint32_t brightnessKey = utils::hash("brightness");
static constexpr uint32_t indicatorLevelKey = utils::hash("indLvl");

// constants
static constexpr uint32_t BRIGHTNESS_RAMP_DURATION_MS = 2000; /// duration of the brightness ramp
static constexpr uint32_t BRIGHTNESS_LOOP_UPDATE_EVERY = 20;  /// frequency update of the ramp

static constexpr uint32_t EARLY_ACTIONS_LIMIT_MS = 2000;
static constexpr uint32_t EARLY_ACTIONS_HOLD_MS = 1500;

// time to block turn off since turn on
static constexpr uint32_t SYSTEM_TURN_ON_ALLOW_TURN_OFF_DELAY = 500;

// pre output light call timing (lamp output starts)
// Starts at system start time
static uint32_t preOutputLightCalled = time_ms();

// Define the state for the main prog state machine
typedef enum
{
  // handle the start logic
  START_LOGIC,

  // Prepare the charging operations
  PRE_CHARGER_OPERATION,
  // Charging, or usb OTG mode
  CHARGER_OPERATIONS,
  // Prepare the light operation
  PRE_OUTPUT_LIGHT,
  // output voltage on, light the led strip and enable user modes
  OUTPUT_LIGHT,
  // close the output safely
  POST_OUTPUT_LIGHT,

  // shutdown state (when set, the board wil shutdown)
  SHUTDOWN,

  // Should never happen, default state
  ERROR,
} BehaviorStates;
const char* BehaviorStatesStr[] = {
        "START_LOGIC",
        "PRE_CHARGER_OPERATION",
        "CHARGER_OPERATIONS",
        "PRE_OUTPUT_LIGHT",
        "OUTPUT_LIGHT",
        "POST_OUTPUT_LIGHT",
        "SHUTDOWN",
        "ERROR",
};
// main state machine
StateMachine<BehaviorStates> mainMachine(BehaviorStates::START_LOGIC);

// system was powered from vbus power event
static bool wokeUpFromVbus_s = false;
bool did_woke_up_from_power() { return wokeUpFromVbus_s; }

// target power on state (not actual state)
static bool isTargetPoweredOn_s = false;
bool is_system_should_be_powered() { return isTargetPoweredOn_s; }
void set_power_on() { isTargetPoweredOn_s = true; }
void set_power_off()
{
  // prevent early shutdown when system is just booting, or lamp jst turns on
  if (time_ms() - preOutputLightCalled < SYSTEM_TURN_ON_ALLOW_TURN_OFF_DELAY)
    return;

  isTargetPoweredOn_s = false;
}

// allow system to be powered if no hardware alert and power is setup
bool can_system_allowed_to_be_powered()
{
  return not(alerts::manager.is_raised(alerts::Type::SYSTEM_IN_ERROR_STATE) or not power::is_setup());
}

// return true if vbus is high
bool is_charger_powered() { return charger::is_vbus_powered(); }

// hold the last time startup_sequence has been called
uint32_t lastStartupSequence = 0;

// hold the boolean that configures if button's usermode UI is enabled
bool isButtonUsermodeEnabled = false;

// hold a boolean to avoid advertising several times in a row
bool isBluetoothAdvertising = false;

// timestamp of the system wake up
static uint32_t turnOnTime = time_ms();

bool read_parameters()
{
  // load values in memory
  const bool isFileLoaded = fileSystem::load_initial_values();

  uint32_t brightness = 0;
  if (fileSystem::get_value(brightnessKey, brightness))
  {
    brightness::update_brightness(brightness, true);
    brightness::update_saved_brightness();
  }

  uint32_t indicatorLevel = 0;
  if (fileSystem::get_value(indicatorLevelKey, indicatorLevel))
  {
    indicator::set_brightness_level(indicatorLevel);
  }

  user::read_parameters();
  return isFileLoaded;
}

void write_parameters()
{
  fileSystem::clear();

  // only save saved brightness, not current
  fileSystem::set_value(brightnessKey, brightness::get_saved_brightness());
  fileSystem::set_value(indicatorLevelKey, indicator::get_brightness_level());

  user::write_parameters();

  fileSystem::write_state();
}

// user code is running when state is output
bool is_user_code_running() { return mainMachine.get_state() == BehaviorStates::OUTPUT_LIGHT; }

/**
 * This turns off the system FOR REAL and enable the interrupt pin for power on
 * DO NOT USE THIS IF YOU ARE NOT SURE, great potential for system brick/lock
 */
void true_power_off()
{
  // stop i2c interfaces
  for (uint8_t i = 0; i < get_wire_interface_count(); ++i)
  {
    i2c_turn_off(i);
  }
  delay_ms(5);

  // disable peripherals
  DigitalPin(DigitalPin::GPIO::Output_EnableExternalPeripherals).set_high(false);
  // disable gates
#ifdef IS_HARDWARE_1_0
  // disable pullup in sleep mode (in V>1.0, done electrically)
  DigitalPin(DigitalPin::GPIO::Input_isChargeOk).set_pin_mode(DigitalPin::Mode::kInput);
  DigitalPin(DigitalPin::GPIO::Signal_BatteryBalancerAlert).set_pin_mode(DigitalPin::Mode::kInput);
#endif
  DigitalPin(DigitalPin::GPIO::Output_EnableVbusGate).set_high(false);
  DigitalPin(DigitalPin::GPIO::Output_EnableOutputGate).set_high(false);

  // deactivate indicators
  indicator::set_color(utils::ColorSpace::BLACK);
  DigitalPin::deactivate_gpios(); // physically disconnect gpios
  delay_ms(1);

  // power down nrf52.
  // on wake up, it'll start back from the setup phase
  go_to_sleep(ButtonPin.pin());

  /*
   * Nothing after this, system is off !
   */

  // if we reach this, the system failed to go to sleep, register may be broken
  alerts::manager.raise(alerts::Type::SYSTEM_OFF_FAILED);
}

void button_disable_usermode() { isButtonUsermodeEnabled = false; }

bool is_button_usermode_enabled() { return isButtonUsermodeEnabled; }
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

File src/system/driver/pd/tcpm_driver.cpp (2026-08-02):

/*
 * tcpm_driver.c
 *
 * Created: 11/11/2017 18:42:26
 *  Author: jason
 */

#include "tcpm_driver.h"

extern const struct tcpc_config_t tcpc_config;

/* I2C wrapper functions - get I2C port / slave addr from config struct. */
int tcpc_write(int reg, int val)
{
  return lampda::hal::i2c::i2c_write8(
          tcpc_config.i2c_host_port, tcpc_config.i2c_slave_addr, reg & 0xFF, (uint8_t)val & 0xFF, 1);
}

int tcpc_read(int reg, int* val)
{
  return lampda::hal::i2c::i2c_read8(
          tcpc_config.i2c_host_port, tcpc_config.i2c_slave_addr, reg & 0xFF, (uint8_t*)val, 0);
}

int tcpc_xfer(const uint8_t* out, int out_size, uint8_t* in, int in_size, int flags)
{
  return lampda::hal::i2c::i2c_xfer(
          tcpc_config.i2c_host_port, tcpc_config.i2c_slave_addr, out_size, out, in_size, in, flags);
}

int tcpc_xfer_unlocked(const uint8_t* out, int out_size, uint8_t* in, int in_size, int flags)
{
  return lampda::hal::i2c::i2c_xfer_unlocked(
          tcpc_config.i2c_host_port, tcpc_config.i2c_slave_addr, out_size, out, in_size, in, flags);
}

void tcpc_lock(int lock)
{
  // TODO check result ?
  if (lock == 0)
    lampda::hal::i2c::unlock_i2c();
  else
    lampda::hal::i2c::lock_i2c();
}

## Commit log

2023-05-08 correct fade in and fade out
    [animations.cpp, constants.h]
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2023-09-24 redesign and code cleanup
    [behavior.cpp, button.cpp, constants.h]
2023-09-24 Add stepped color, correct brightness computation
    [behavior.cpp]
2023-09-24 Add led disable pin and battery level monitoring
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2023-09-27 Reset colors when color category change is signal
    [behavior.cpp]
2023-10-11 reset state when entering error mode
    [behavior.cpp]
2023-10-12 correct some wheel and animation bugs
    [animations.cpp, behavior.cpp]
2023-10-12 Add slow party color noise
    [animations.cpp, behavior.cpp]
2023-10-12 add smoothing on noise
    [animations.cpp, behavior.cpp]
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2023-10-19 wrap the adafruit class to prevent color mismatch
    [animations.cpp, behavior.cpp, constants.h]
2024-01-03 Add battery saving features, slow heartbeat on lamp off
2024-03-01 Animation corrections and buffer adjustements
    [animations.cpp, constants.h]
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2024-03-04 Use coordinate mapping, and move to 3D noise for animations
    [animations.cpp, behavior.cpp, button.cpp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]
2024-03-04 Add correct 3d coordinate mapping
    [animations.cpp, behavior.cpp]
2024-03-04 Adjust max power consumption by reducing max brightness
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2024-03-08 Repare a strange bug where a global static variable get rested randomly
    [behavior.cpp]
2024-03-08 Add correct sound analisys
    [behavior.cpp]
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2024-03-11 Replace strip clear with fadeout in most cases
    [animations.cpp, behavior.cpp]
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2024-05-09 Add electrical design documents
    [BOM_Lampda-micro_v1.csv, PickAndPlace_PCB_Lampda-v1.csv]
2024-05-14 Resolve charging animation bug
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2024-05-16 Add end of charge correct condition
2024-05-17 Use correct shutdown command, use brightness limiter
    [behavior.cpp, button.cpp, constants.h]
2024-05-17 reset led driver at startup, clamp brightness down
    [behavior.cpp]
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2024-05-17 Dont run code if ward was resetted by watchdog
    [behavior.cpp]
2024-05-18 Dont reset the firmware if lampe is not plugged
    [behavior.cpp]
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2024-06-13 use FUSB302 power negociation
    [BOM_Lampda-micro_v1.csv, BOM_Lampda_v1.csv, PickAndPlace_PCB_Lampda-v1.csv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]
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2024-07-19 Switch mode to on when startup sequence is done
2024-07-19 Update electrical design files
    [BOM_Lampda_2024-07-19.csv, BOM_Lampda_v1.csv, PCB_Lampda_2024-07-19.pcbdoc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]
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2024-07-22 Correct PD negocation for charging
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2024-08-07 temporary fix for charger process, waiting for circuit v1.1
    [behavior.cpp]
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2024-08-23 wake up from vbus now triggers a timer before shutdown
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2024-10-25 Expose raw "button state" to user
    This is a refactoring to centralize all the values used
    inside a "ButtonStateTy" structure, of which an user may
    get a copy, using "get_button_state", for raw processing
2024-10-30 optimize write to the correct number of bytes
    [behavior.cpp, constants.h]
2024-11-01 Replace relative includes by absolute ones
    [animations.cpp, behavior.cpp, button.cpp]
2024-11-04 add safe battery level, limit charger functio calls
2024-11-04 correct battery safe voltage regulation
    [constants.h]
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2024-11-04 Add power creep charge mode, alert user in case of slow charging
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2024-11-18 fix and clear the battery read from voltage divider
    [behavior.cpp, constants.h]
2024-11-21 Fix bug #38, prevent button reset each loop turns
    [behavior.cpp, button.cpp]
2024-11-22 change && for and, correct early action logic
    [behavior.cpp, button.cpp]
2024-11-26 Correct slow charge trigger, correct latch on full charge, add hardware alerts
    [behavior.cpp, charging_ic.cpp]
2024-11-26 Do not handle alerts in the first milliseconds
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2024-11-26 Use battery safe levels instead of max levels
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2024-11-27 correct all pd warnings
    [FUSB302.c, tcpm_driver.cpp]
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2024-12-02 Repare refuse to sleep bug
    [behavior.cpp, charging_ic.cpp]
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2025-01-13 Small fixes to includes
    [button.cpp]
2025-01-15 Add dynamic parameter file, refacto prints
    [simulation_parameters.txt]
2025-01-17 correct alert management, clean up simulator logic
    [behavior.cpp, charging_ic.cpp]
2025-01-17 FIXBUG: i2c/serial misstakes
2025-01-20 Add longer debounce check to the startup charging state
2025-01-23 Replace battery ramp with the curve
    [animations.cpp, behavior.cpp, cct_functions.cpp]
2025-02-03 refactor battery curve to work directly on voltage
2025-02-12 use a special charging command for the low battery alerts
2025-02-25 Correct some register values
    [charging_ic.cpp]
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2025-03-29 Update hardware to 1.1
    [BOM_Lampda_2024-07-19.csv, BOM_Lampda_V1_1.csv, Lampda_PCB_V1_1.pcbdoc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]
2025-04-03 Fixe power gate startup delays
    [behavior.cpp]
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2025-04-13 Better stability delay, i2c setup
    [global.cpp, i2c.cpp]
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2025-04-13 Quick start OTG on power swap
    [FUSB302.c, behavior.cpp, charging_ic.cpp]
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2025-04-13 Enable power swap bases
    [FUSB302.c, behavior.cpp, constants.h]
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2025-04-15 Repare blip shutdown bug
    [behavior.cpp, cct_functions.cpp]
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2025-04-18 deactivate source when ping fails
    [global.cpp, tcpm_driver.cpp, threads.cpp]
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2025-06-08 Add back basic bugged imu fluid animation
    [charging_ic.cpp, imu.cpp]
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2025-06-08 Correct 3D lamp coordinates
    [constants.h]
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2025-06-13 Correct led/meter measurment
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2025-06-27 Resolve 113: button click start detection
    [behavior.cpp, button.cpp, constants.h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]
2025-06-27 Fix text speed per char, fix simulator button
    [animations.cpp]
2025-06-30 Do not turn out the power immediatly after writting a strip clear
2025-07-02 Link github issues to TODO
    [behavior.cpp, charging_ic.cpp, tcpm_driver.cpp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]
2025-07-05 #137 Add 3D lamp elements
    [Lampda-LowerPart.stl, Lampda-Poles.stl, Lampda-TopLarge.stl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]
2025-07-06 Complete the doc on assembly
    [Lampda-LowerPart_no_logo.stl, Lampda-Poles.stl, Lampda-Top.stl]
2025-07-16 Fix README.md & .gitignore
    Two changes:
    - don't tell new users to immediately build the WHOLE project*
    - the .gitignore was modified without an ending newline
    *the first step is cloning the repo, then we talk about deps &
    stuff like the arduino-cli, jumping straight to "make verify-all"
    is just likely to confuse users & produce a large error message
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2025-07-23 Update circuit to version 1.1
    [BOM_Lampda_V1_1.csv, Lampda_PCB_V1_1.pcbdoc, Lampda_schematics_V1_1.schdoc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]
2025-08-01 Add features to simulator +small refacto
    [simulation_parameters.txt]
2025-08-03 Use custom ramp circle animation by default
    This will badly interfere with "legacy" modes that directly
    access the strip object, as we won't be able to "intercept"
    their setPixelColor() instruction :/
    (this should cause some flicker until modes switch to LampTy)
2025-08-03 Make 4x fav. anim. immediate to avoid confusion
    Some users, without immediate feedback, don't trigger fav
    config properly. Add a "step" where no fav slot is selected
    but still animated, to get users to wait a bit more for setup
2025-08-08 Resolve strip flash on shutdown
    [behavior.cpp]
2025-08-08 Add an alert if the system fails to go to sleep
    [behavior.cpp]
2025-08-08 Add alert to handle error state
    [behavior.cpp]
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2025-08-13 Adapt crash threshold to access bigger programs
    [behavior.cpp, global.cpp]
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2025-08-20 Add hardware & software error details for charger ic
    [behavior.cpp, charging_ic.cpp]
2025-08-20 Prevetn system shutdown lock when hardware error is raised
    [behavior.cpp]
2025-08-20 fix i2c command
2025-08-21 Use correct functions for watchdog
    [behavior.cpp, constants.h, global.cpp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]
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2025-08-21 Avoid temperature register spamming
    [registers.cpp]
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2025-08-28 minor test correction in pd state
    [FUSB302.c, behavior.cpp]
2025-08-28 Add safety to prevent thread crash
    [FUSB302.c, behavior.cpp, threads.cpp]
2025-08-28 Resolve power switch when asked by user, remove automatic power switch
    [FUSB302.c]
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2025-08-28 resolve get power source capabilities on suspend resume
2025-08-29 Resolve lampda_print function duplication
    [behavior.cpp, charging_ic.cpp, imu.cpp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]
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2025-08-29 Resolve power switch falls in error state
    [behavior.cpp, constants.h]
2025-08-29 Resolve very rare software error on usbc unplug
    [charging_ic.cpp]
2025-09-07 Resolve button stuck in software bug
    [button.cpp]
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2025-09-07 Resolve missing mutex & missplaced enter/quit mode
    [i2c.cpp]
2025-09-07 resolve early actions removal
    [behavior.cpp]
2025-09-09 Migrate perlin noise mode
    [animations.cpp, behavior.cpp]
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2025-09-12 resolve end of charge lamp turn off
    [charging_ic.cpp]
2025-09-12 prevent system turn off when output just turned on
    [behavior.cpp]
2025-09-12 kick watchdog in error state
    [behavior.cpp]
2025-09-12 state machine force update state & charger go to error mode
    [behavior.cpp]
2025-09-12 prevent fake double click on startup
    [behavior.cpp, button.cpp]
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2025-09-21 Correct correct voltage range in rgb lamps
    [cct_functions.cpp, constants.h]
2025-09-25 Add wake up in favorite mode, resolve wrong button press on start
    [button.cpp]
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2025-09-25 Correct start button click not registered
    [button.cpp]
2025-09-29 Prevent shutdown and auto turn off when certain alerts are set
    [behavior.cpp]
2025-09-29 Resolve low battery alert on start
    [behavior.cpp]
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2025-10-02 Add charge mock to simulator
    [simulation_parameters.txt]
2025-10-02 Handle BQ25713 mock instructions
    [simulation_parameters.txt]
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2025-10-04 prevent flash on sunset turn off
    [behavior.cpp]
2025-10-04 prevent sunset update of sunset timer on button release
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2025-10-04 bubbles improvements
    better calibrate colors fading and decide their death from it
2025-10-04 Fix duplicate pushbutton entry in BOM
2025-10-05 Capture threads functions correctly
    [threads.cpp]
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2025-10-08 Add errors on API overload
    [TextLangage.py, lampda_gui.py, lampda_serial.py]
2025-10-09 Prevent port use when target alerts are high
    [behavior.cpp]
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2025-10-20 Resolve warnings in code
    [behavior.cpp, charging_ic.cpp, constants.h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]
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2025-11-23 Resolve occasional false read on battery level start
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2025-12-07 Prevent and disable battery alerts when battery readings are incoherent
2025-12-07 Add missing battery alert
    [behavior.cpp]
2025-12-10 Fix lamp crashing due to file system
    [charging_ic.cpp, global.cpp]
2025-12-10 Add filesystem shutdown, add charge error alert
    [behavior.cpp, charging_ic.cpp, global.cpp]
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2025-12-20 Use correct imu handler in nudz modes
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2026-01-25 Add more error case on power components
    [charging_ic.cpp]
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2026-03-15 Add a command to toggle the button pin [patch for burned pins
    [behavior.cpp, button.cpp, gpio.cpp]
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2026-04-22 Resolve minor sunset timer bugs
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2026-05-02 Add blue noise to color correction
    [constants.h]
2026-05-02 Resolve vbus voltage drop on charge, resolve battery associated TODO
    [charging_ic.cpp]
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2026-05-04 Add 20 clicks to fully reset the lamp
    [behavior.cpp]
2026-05-04 Add 13H for user parameters reset
    [behavior.cpp]
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2026-05-08 Add ELK programmable color modes & all fixed color mode
    [cct_functions.cpp]
2026-05-13 Add clearer errors on battery recovery mode
    [behavior.cpp]
2026-05-18 434: resolve power gate switch timeout
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2026-05-20 Correct thread usage with uint32 instead of names
    [behavior.cpp, global.cpp, threads.cpp]
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2026-07-08 Correct thread integration in mocks
    [behavior.cpp, threads.cpp]
2026-07-08 Use correct print function and mutex
    [global.cpp]
2026-07-08 Cleanup and correction of button event queues
    [button.cpp]
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2026-07-14 track the filesystem crash #353
    [global.cpp]
2026-07-14 #405: resolve invalid ble battery level
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2026-07-22 Fix simulator no battery warning
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2026-07-30 correction format + fix mistake in variable name
    [behavior.cpp]
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2026-08-02 Prevent battery mode from immediatly stopping
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2026-08-26 Rework ssystem shutdown procedure
    [behavior.cpp, button.cpp, threads.cpp]
2026-08-27 Resolve #477 crash on shutdown
    [behavior.cpp, threads.cpp]
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2026-09-02 Fix button toggle behavior
    [button.cpp]
2026-09-07 Declutter the principal folders
    [BOM_Lampda_V1_1.csv, Lampda-LowerPart.stl, Lampda-LowerPart_no_logo.stl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]
2026-09-07 Repare filesystem memory usage bug
    [filesystem.cpp]
2026-09-10 418 ble advertize to paired user (#506)
    * Use secure pairing for ble validation
    * Resolve bluetooth crash on filesystem format
    * Add safeties around secured BLE connection
    * Fast reject unauthorized BLE devices
    * Use bluetooth pairing button during pairing only
    * BLE standard activation on 1H, than pairing mode on 1H
    [behavior.cpp, filesystem.cpp, global.cpp]
2026-09-16 Add new cli commands (#512)
    * Add set favorite command
    * Add set favorite command
    * use a clean wrapper for favorite exit
    * Allow user to type commands with a space in simulator
    * Cleaner user parameter deletion
    * Reset statistics on filesystem format
    ---------
    [behavior.cpp, filesystem.cpp]
2026-09-21 357 battery mode stopping randomly for some devices (#513)
    * Refactor FUSB302 vbus driver read
    * Gracefully exit external battery mode
    * Add mutex in FUSB302 driver, Add mutex HAL
    * Cleanup PD code and detection threshold
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2026-09-27 Repare HAL ble layer: remove dynamic memory & correct warnings
    [ble.cpp]
2026-09-28 Correct BLE start on adveertise start
    [ble.cpp]
2026-09-30 correct some problems in BLE hal
    [ble.cpp]
2026-09-30 Remove BLE MITM safety, add error cheks and types
    [ble.cpp]
2026-10-01 Replace std::string with static_string
    [behavior.cpp, charging_ic.cpp]
2026-10-06 Identify the crash on the latest develop: incorrect filsystem format
    [filesystem.cpp]
2026-10-07 Repare wrong error message lenght
    [simulation_parameters.txt]
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2026-10-21 Total refactoring of the led masking system, more reliable & stable in time
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2026-10-31 Add user action signals on serial and bluetooth outputs
    Emit stable one-line signals when brightness, active mode, custom ramp
    or indicator level change, so external apps can track the lamp state.
    Fixes #562
2026-10-31 Handle remarks: shorter signal names, line end in print call
    Refs #562
2026-11-02 fix(modes): enter once when jumping to a favorite index
    jump_to_new_active_index called set_active_group then set_active_mode,
    and each path enters the mode, so switching favorites emitted two \$mode
    user actions for one change. Quit once, apply group/mode, enter once.
    Keep develop's ramp-restore comparison.
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2026-11-03 Correct probe check event when recovery mode is not active yet
2026-11-04 Raise hardware error on imu fail
2026-11-04 Clear sunrise timer with the correct brightness
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2026-11-06 Fix sunset timer canceling
2026-11-07 Resolve multiple calls to power component shutdown
2026-11-08 #607 Fix 64-bit serial number and uint32 print formats
2026-11-08 #623 Check print formats at compile time and fix uint32 mismatches
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2026-11-08 #619 Fix thread creation failure check and suspended flag
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2026-11-08 Fix alert & blip edge case
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2026-11-09 #604 Release the alert brightness limit when its alert clears
    The max brightness was only restored once every alert was cleared: after a
    BATTERY_LOW or TEMP_TOO_HIGH alert cleared, the output stayed clamped while any
    unrelated alert (sunset timer, bluetooth advertising, lockout...) was raised.
    Each alert now declares its brightness limit, and handle_all() applies the
    lowest limit of the raised alerts on every turn.
2026-11-09 #613 Test that a blip after a power gate disable is refused
    The fix itself landed in 7192cf3d (disable_power_gate() clears
    _isPowerGateReallyEnabled). Its existing test only covered a blip already
    running at the disable: cover a blip requested after the gates were disabled,
    and while the vbus gate switches on. Both fail without the fix: the blip
    timeout forced the output gate on again.
2026-11-09 #602 Synchronize the button event queue and button state
    The button event queue was pushed by the button thread and popped by the main
    loop without any lock, and an end of hold event was pushed without checking
    that the queue was full (assert in etl::queue).
    - the queue is private to inputs.cpp, and only accessed under a mutex through
    push/pop helpers. The button callbacks run without the lock.
    - every push checks that the queue is not full.
    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
2026-11-09 #615 Make the power state machine thread safe
    The power state machine is run by the power thread, while the go_to_*()
    requests set its state from the main loop, without any lock. set_state() with a
    timeout also activated the timeout before setting its delay and target: a
    concurrent run() could jump at once to the previous target, skipping the rails
    clearing.
    - StateMachine is synchronized by an internal mutex, and sets the timeout
    delay and target before activating it.
    - switch_state() checks the error state and switches atomically
    (set_state_unless): an error raised by the power thread is never
    overwritten by a main loop request.
    - the rails clearing only skips its timeout if the stat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
2026-11-09 Defer the USB port fault alert out of its interrupt
    The USB protection fault interrupt raised USB_PORT_SHORT directly:
    AlertManager_t::raise() takes a blocking mutex when the alert is already raised
    (invalid in interrupt context, and the unlock could release a lock owned by a
    task), updates the statistics and prints.
    The interrupt now only sets an atomic flag (signal_usb_port_fault()).
    process_interrupt_signals() raises or refreshes the alert from a thread: it runs
    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
2026-11-09 Resolve bad register clear on charge
2026-11-09 #357 Detect PD sinks in source mode despite the board Rd
    All boards have a permanent 5.1k Rd on both CC lines. In battery mode
    (source), the standard FUSB302 thresholds read it as an attached sink:
    the lines were never seen open, attachments were taken for a debug
    accessory with a fixed polarity, detachments were missed, and PD sinks
    (phones, another lamp) never got a contract.
    - CC thresholds scaled to the Rp current and placed between the board
    Rd alone, board Rd || sink Rd, and board Rd || Ra (cc_thresholds.h)
    - advertise a 3A Rp, so the sink still reads a valid Rp through the
    board Rd
    - measure each CC line with its own pull-up only, and once attached keep
    the pull-up only on the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
2026-11-09 #357 #642 Fix the PD state machine freezes
    The emulated task layer slept the PD thread with vTaskSuspend, and a
    scheduler thread woke it with vTaskResume. An event raised between the
    timeout arming and the suspension (FUSB302 interrupt) made the scheduler
    resume a thread that was not suspended yet: FreeRTOS drops it, and the
    PD thread then slept forever, until a reboot.
    - the PD thread now sleeps on its own task notification, set by
    task_set_event: a notification is latched, a wake up cannot be lost.
    The scheduler thread is removed (saves its stack)
    - task_wait_event_mask: the remaining time underflowed after the
    deadline, and became an infinite wait
    - mask the BC_LVL interrupt as a s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
2026-11-09 #357 Add USB-C PD diagnostics to the pd command
    - timeline of the last 32 PD events (states, messages sent and received
    with their GoodCRC result, hard resets)
    - source side counters (attach, capabilities sent and acked, contracts)
    - raw CC voltages, Rp and thresholds, FUSB302 transmission results
    - time since the last PD state machine run (detects a frozen thread)
    - the contract line shows what the sink requested when we are a source
2026-11-09 #357 Cut VBUS during a PD hard reset in battery mode
    As a source, a hard reset requires VBUS to drop to vSafe0V during the
    recovery time, then come back to vSafe5V. Battery mode kept 5V on the
    port: the sinks waited for the drop, then sent hard resets again until
    they gave up on PD.
    - open the VBUS gate while the source is in a hard reset, the OTG output
    stays on (back to its default voltage) to restore VBUS in time
    - after the reset, keep the gate open until the charger output is back
    near the default voltage (the contract may have been at 20V)
    - do not take the cut and the renegotiation for an OTG inactivity
2026-11-09 #357 Trim the PD diagnostics
    Remove the debug tools only needed for the investigation: the PD event
    timeline buffer, and the raw CC voltage measure (it switches the PD
    receiver line, and can lose a message).
    Keep the source counters, the transmission results and the last state
    machine run time in the pd command.
2026-11-09 Reenable power role swap
2026-11-09 #357 Add a compile gate for the board permanent CC Rd
    LMBD_USBC_HAS_BOARD_CC_RD, in src/user/constants.h: 1 for the current boards (permanent 5.1k Rd on both CC lines).
    Set to 0 for a USB-C port without it: the FUSB302 source thresholds and the Rp (1.5A) go back to the standard ones.
    The gate cannot be set from the build flags: they do not reach the C files, and the FUSB302 driver would disagree
    with the PD configuration.
2026-11-10 #357 Power a dual role laptop from the battery mode
    A dual role laptop could not use the lamp as a power source:
    - VBUS collapsed on the 5V to 20V step, the laptop detached
    - VBUS was driven before any sink was attached, a non compliant source
    - a laptop with a 3A Rp of 4.7k to 3.3V reads our Rp in parallel with
    the board permanent Rd as a sink, and powers VBUS itself
    - at 20V, the VBUS gate signals a fault and cuts VBUS as soon as the
    laptop starts to draw
    Battery mode:
    - keep the VBUS gate off until the PD stack sees a sink
    - when the partner powers VBUS, attach as a sink (5V only, without using
    that power) and ask for the source role by a power role swap
    - ramp the output voltage u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
